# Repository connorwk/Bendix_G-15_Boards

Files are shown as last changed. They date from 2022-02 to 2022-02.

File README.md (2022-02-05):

# Bendix G-15 Boards
KiCad re-creations of the schematics and boards for the Bendix G-15.

These boards are meant to be functional drop in replacements for the original boards, whether they are damaged or missing.
The idea is either:
- To drill out the rivets on the original card's frames, desolder the wires for the tube sockets/etc and rivet/solder in the new board.
- Build up oragami PCBs to build a card frame.

Currently the goal is to get all schematics and boards layed out for the G-15 CPU and get a CPU at the System Source Computer Museum up and running using replacement boards.

## TODO
- Find suitable replacement diodes/transistors. This will be determined by component parameter analysis, specification comparison, and functional testing of boards with replaced components.
- Add oragami PCBs to allow building your own card handles to assemble around the boards.

## References
Documentation for the Bendix G-15 can be found here:
http://bitsavers.org/pdf/bendix/g-15/

The document used for schematics is:
http://bitsavers.org/pdf/bendix/g-15/G15D_Tech_Man_Rev1_Part1.pdf

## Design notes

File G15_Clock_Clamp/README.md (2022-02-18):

# Clock Clamp, For Bendix G-15 CPU
[Schematic](G15_Clock_Clamp_Schematic.pdf)

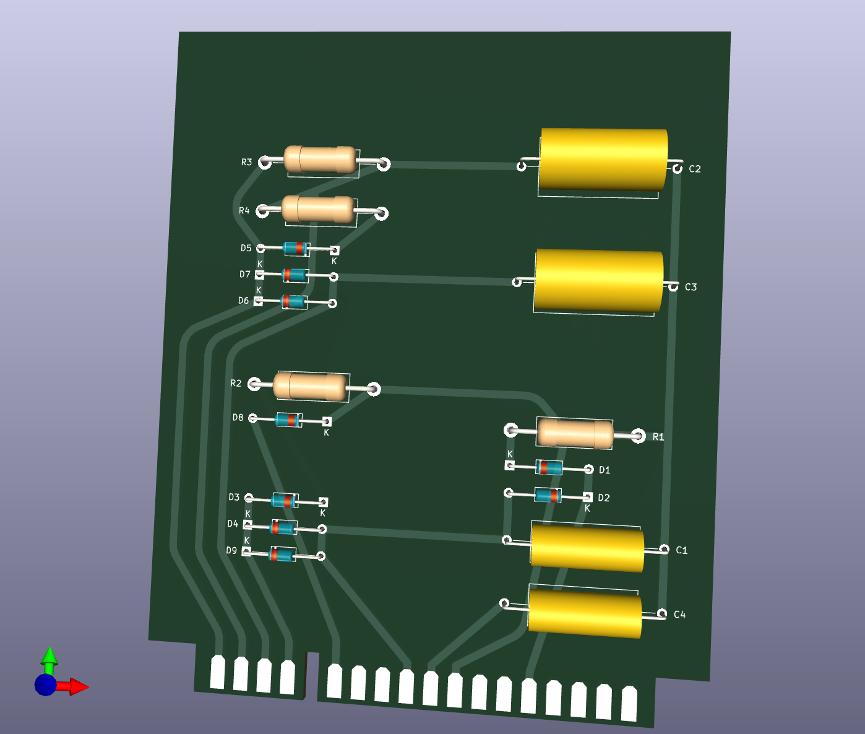
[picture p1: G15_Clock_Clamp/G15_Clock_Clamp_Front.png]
Front

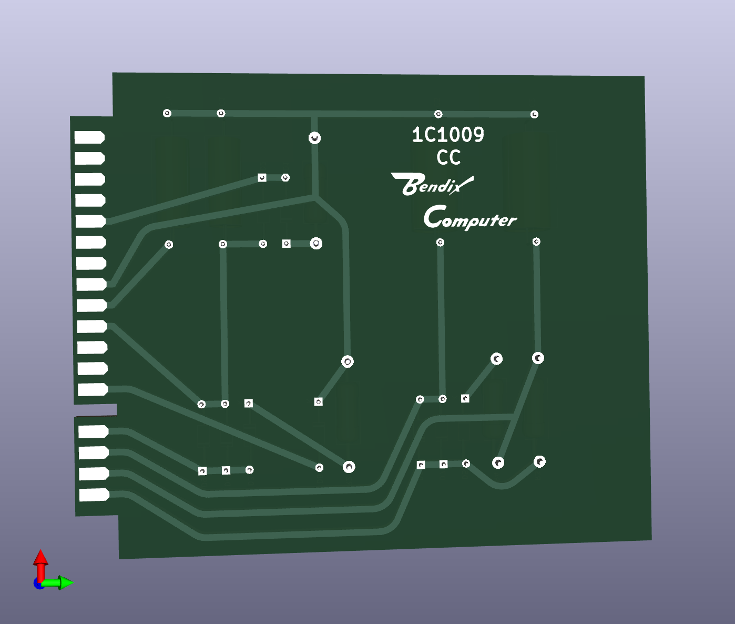
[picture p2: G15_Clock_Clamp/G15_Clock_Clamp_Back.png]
Back


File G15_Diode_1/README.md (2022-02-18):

# Diode 1, For Bendix G-15 CPU
[Schematic](G15_Diode_1_Schematic.pdf)

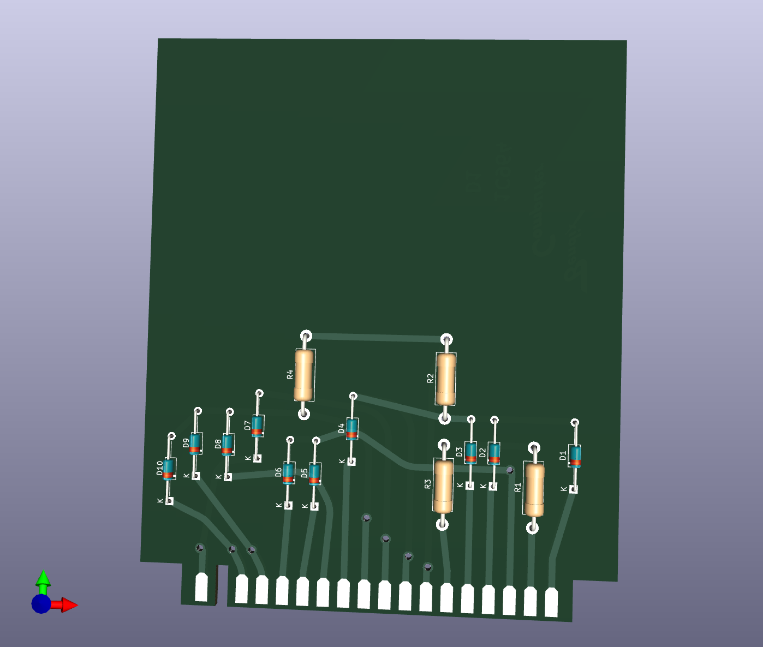
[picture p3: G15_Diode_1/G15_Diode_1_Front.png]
Front

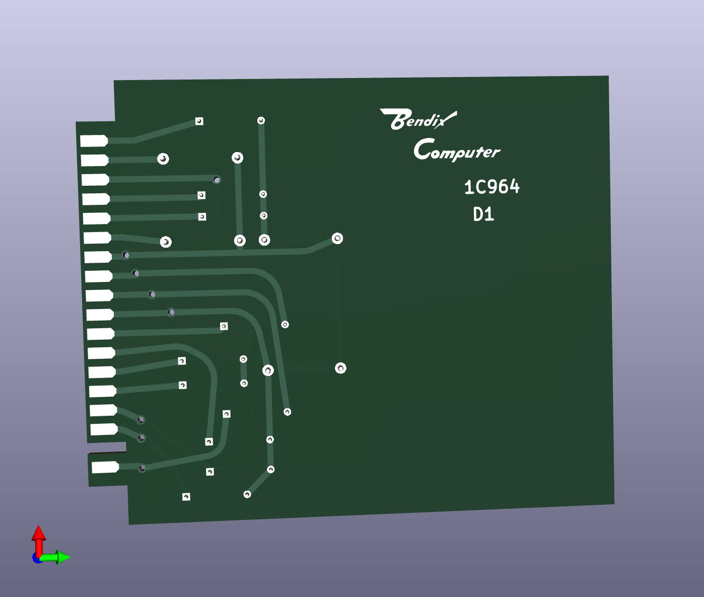
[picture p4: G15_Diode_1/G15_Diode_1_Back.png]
Back


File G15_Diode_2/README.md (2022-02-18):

# Diode 2, For Bendix G-15 CPU
[Schematic](G15_Diode_2_Schematic.pdf)

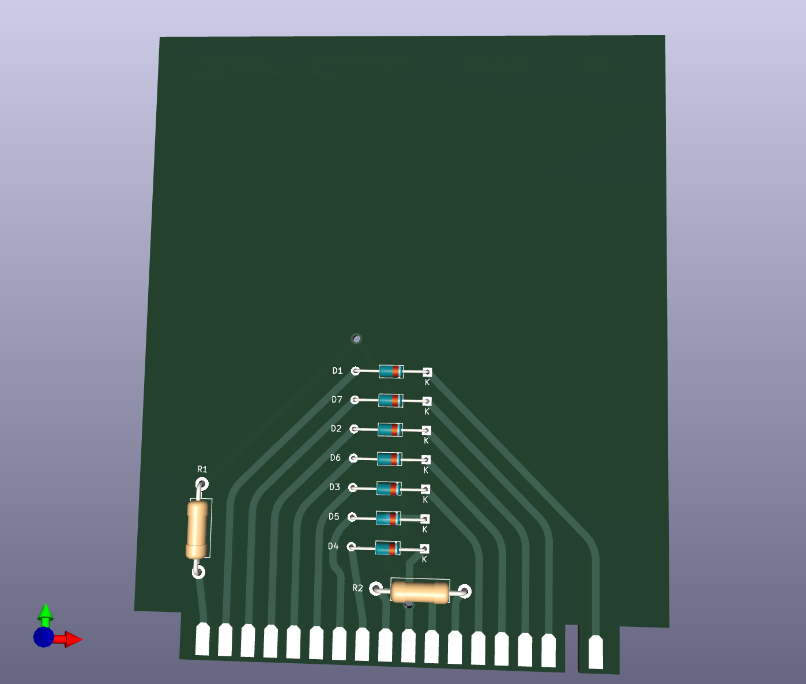
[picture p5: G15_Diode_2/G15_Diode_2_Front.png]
Front

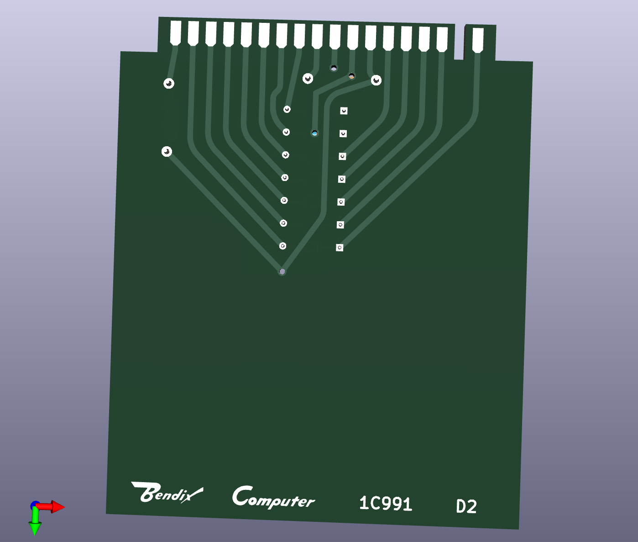
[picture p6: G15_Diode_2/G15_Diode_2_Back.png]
Back


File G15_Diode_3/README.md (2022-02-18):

# Diode 3, For Bendix G-15 CPU
[Schematic](G15_Diode_3_Schematic.pdf)

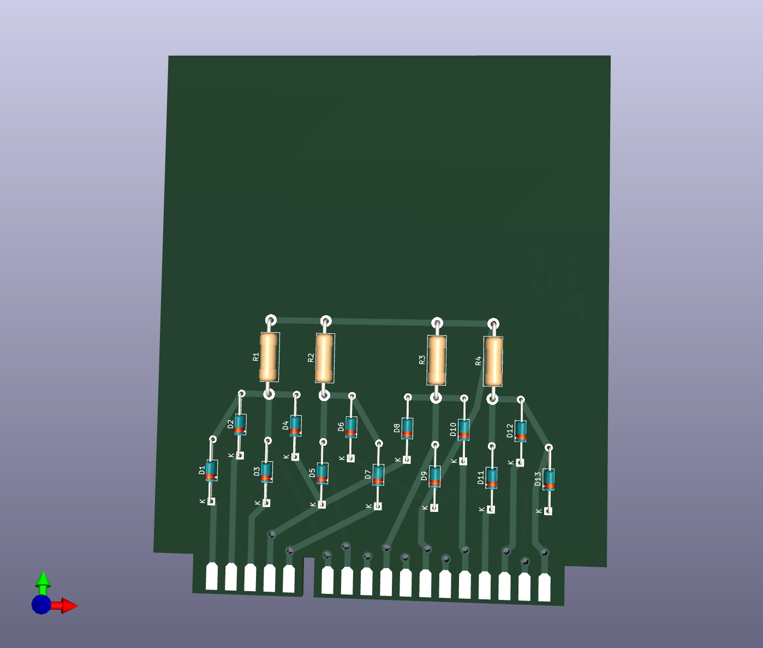
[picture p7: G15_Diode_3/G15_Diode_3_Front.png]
Front

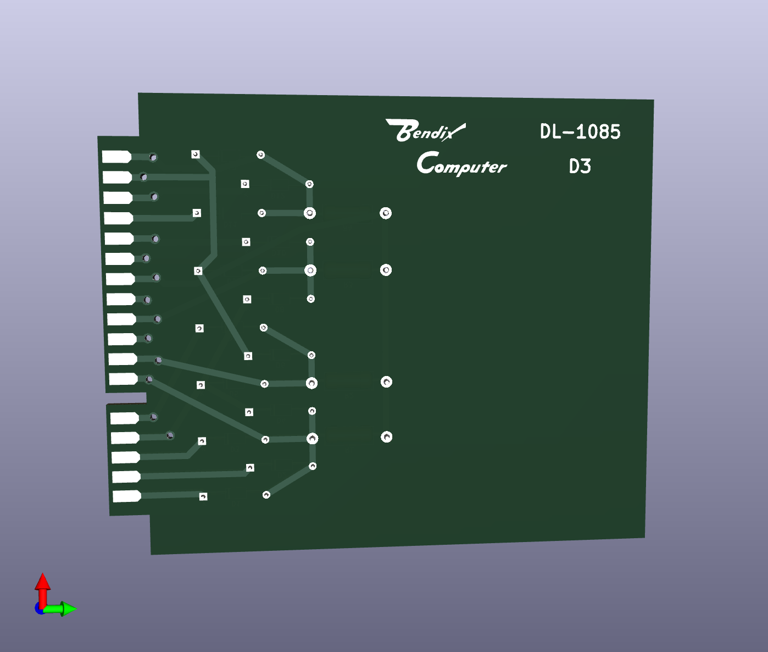
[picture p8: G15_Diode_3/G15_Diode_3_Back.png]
Back


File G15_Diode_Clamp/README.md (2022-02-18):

# Diode ClamP, For Bendix G-15 CPU
[Schematic](G15_Diode_Clamp_Schematic.pdf)

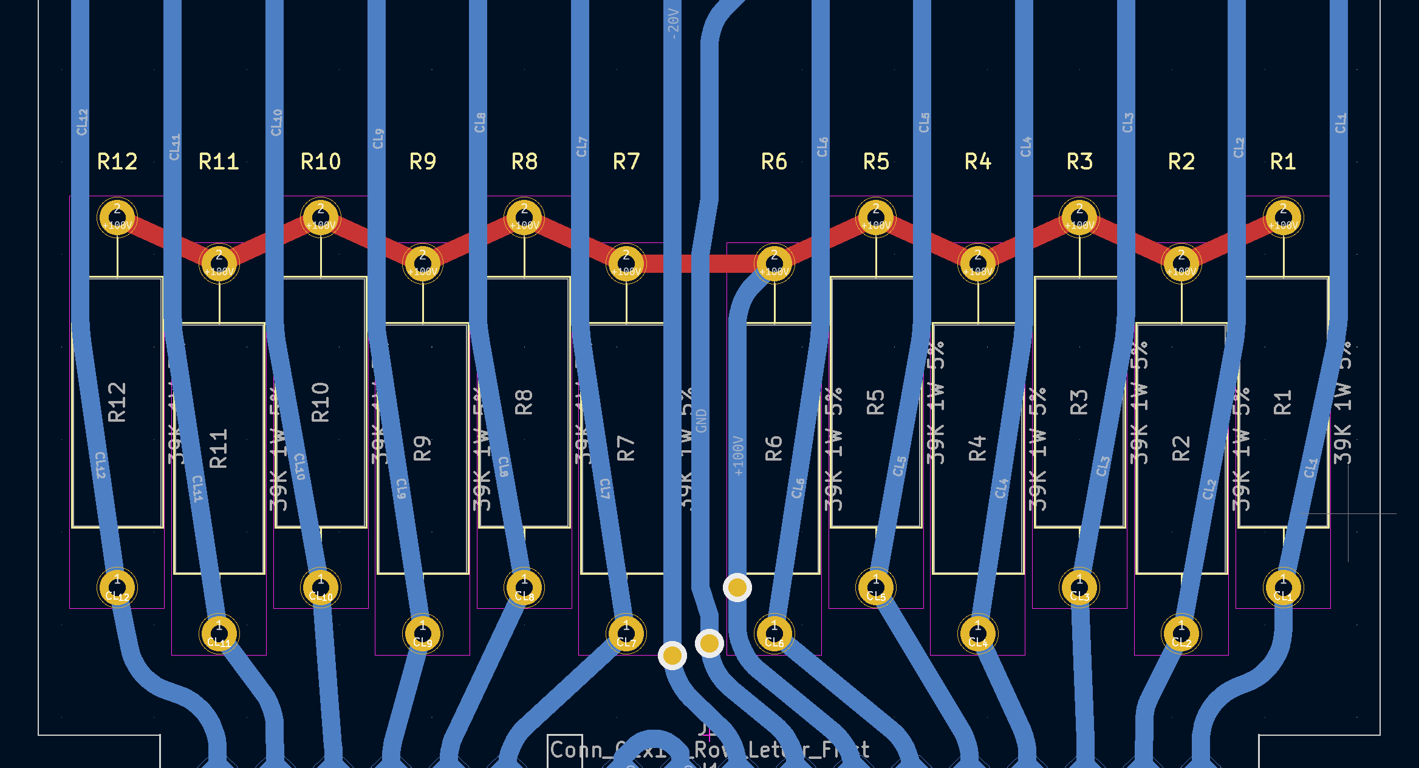
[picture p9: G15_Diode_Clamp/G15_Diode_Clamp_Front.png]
Front

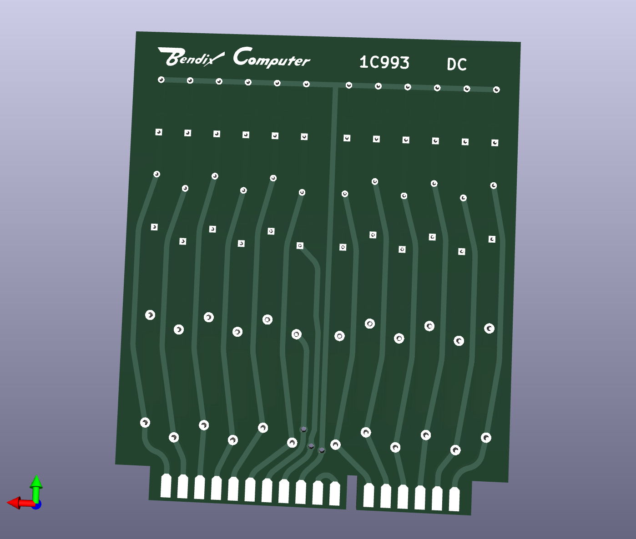
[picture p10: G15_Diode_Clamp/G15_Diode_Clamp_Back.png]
Back


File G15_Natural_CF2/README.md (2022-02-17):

# Cathode Follower 2, Natural Handle, For Bendix G-15 CPU
[Schematic](G15_Natural_CF2_Schematic.pdf)

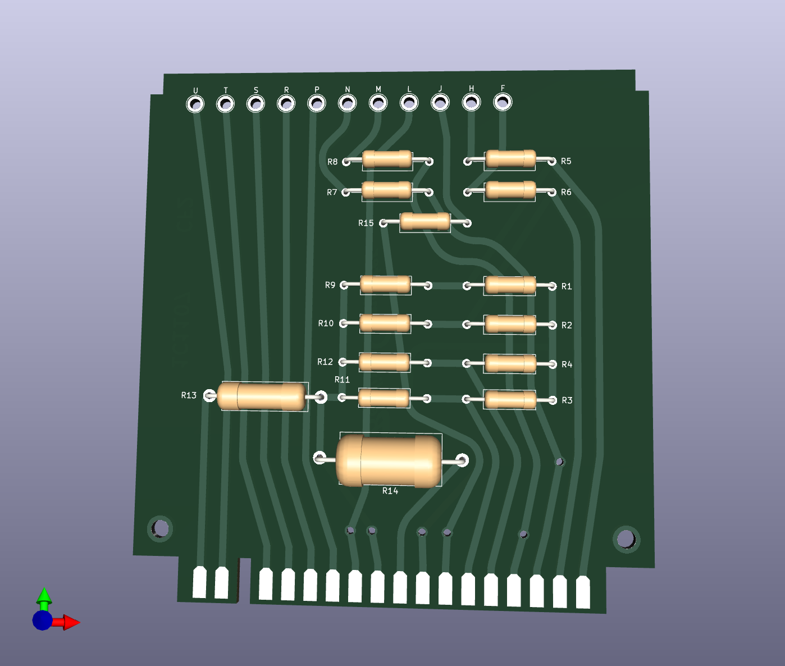
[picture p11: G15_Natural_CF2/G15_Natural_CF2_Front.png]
Front

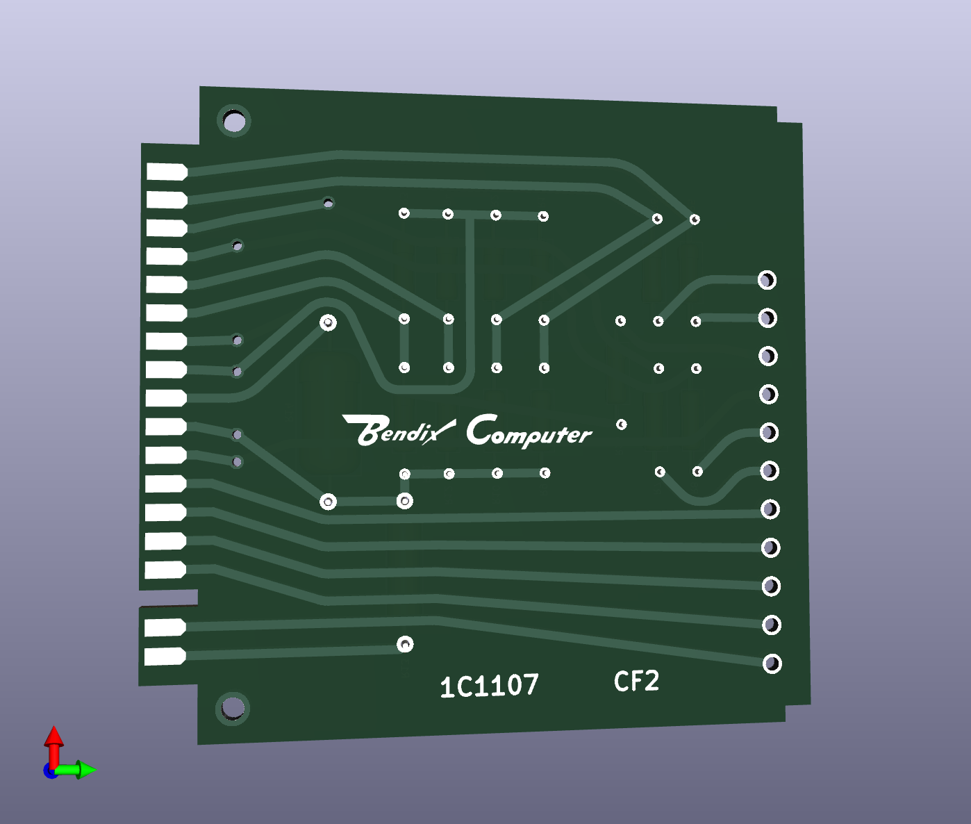
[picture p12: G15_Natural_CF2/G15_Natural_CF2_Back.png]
Back


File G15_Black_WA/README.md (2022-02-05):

# Write Amplifier, Black Handle, For Bendix G-15 CPU
[Schematic](G15_Black_WA_Schematic.pdf)

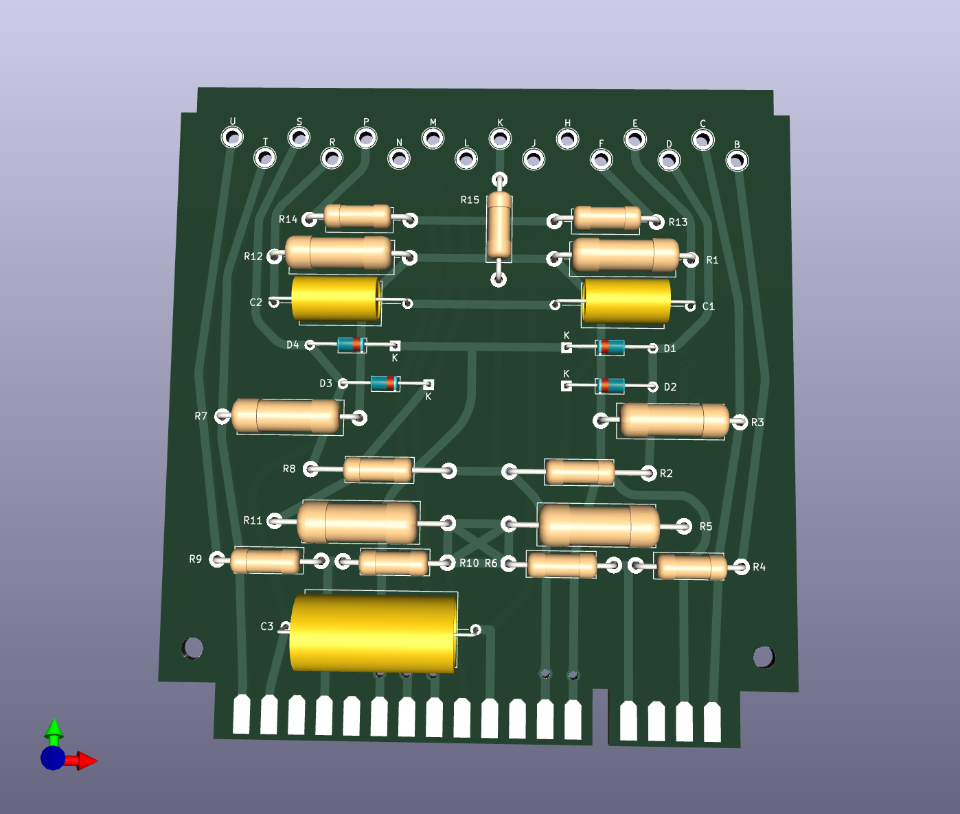
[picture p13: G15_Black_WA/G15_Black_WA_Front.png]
Front

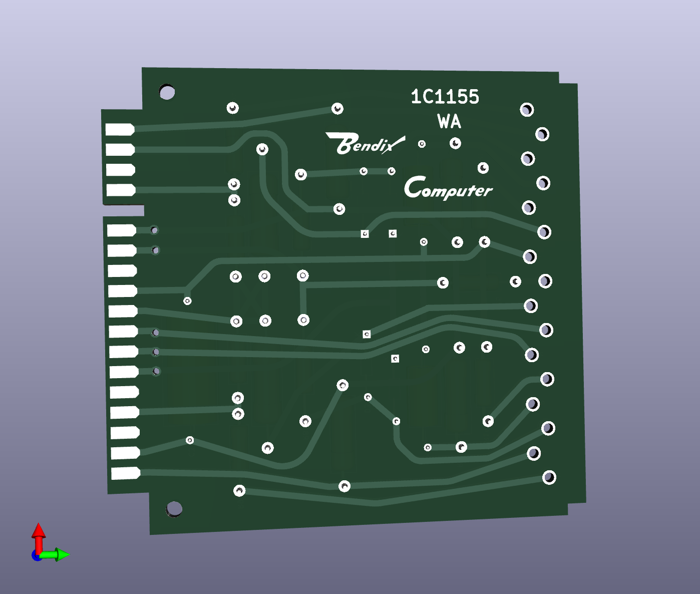
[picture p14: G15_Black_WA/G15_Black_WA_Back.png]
Back


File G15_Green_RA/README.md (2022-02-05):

# Read Amplifier, Green Handle, For Bendix G-15 CPU
[Schematic](G15_Green_RA_Schematic.pdf)

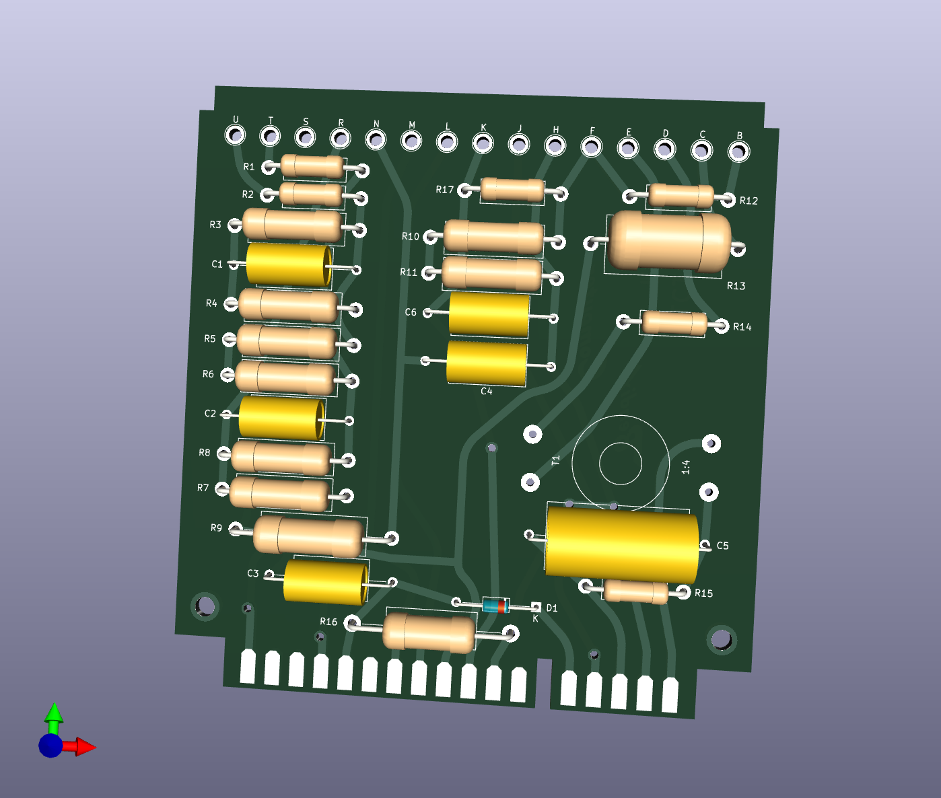
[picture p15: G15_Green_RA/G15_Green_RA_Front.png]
Front

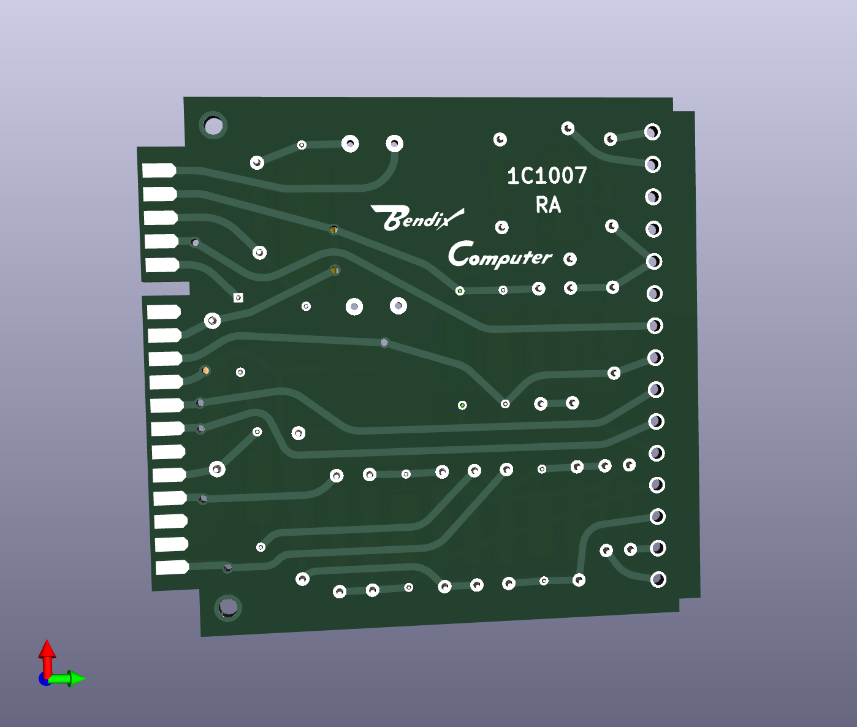
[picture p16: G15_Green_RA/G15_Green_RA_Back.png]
Back


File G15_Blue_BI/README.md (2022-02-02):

# Buffer Inverter, Blue Handle, For Bendix G-15 CPU
[Schematic](G15_Blue_BI_Schematic.pdf)

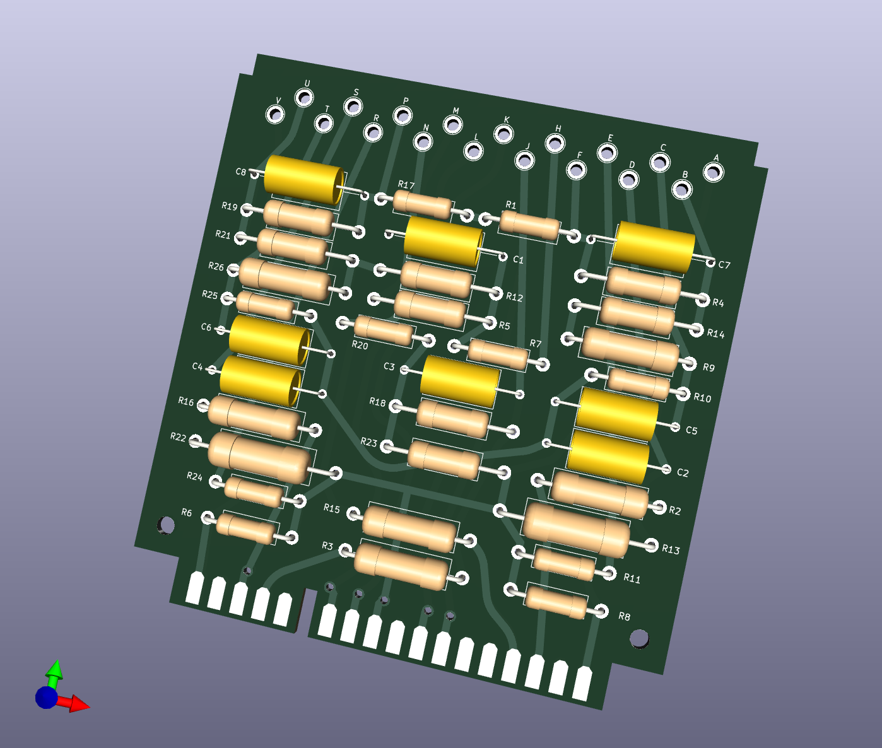
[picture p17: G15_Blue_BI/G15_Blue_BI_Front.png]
Front

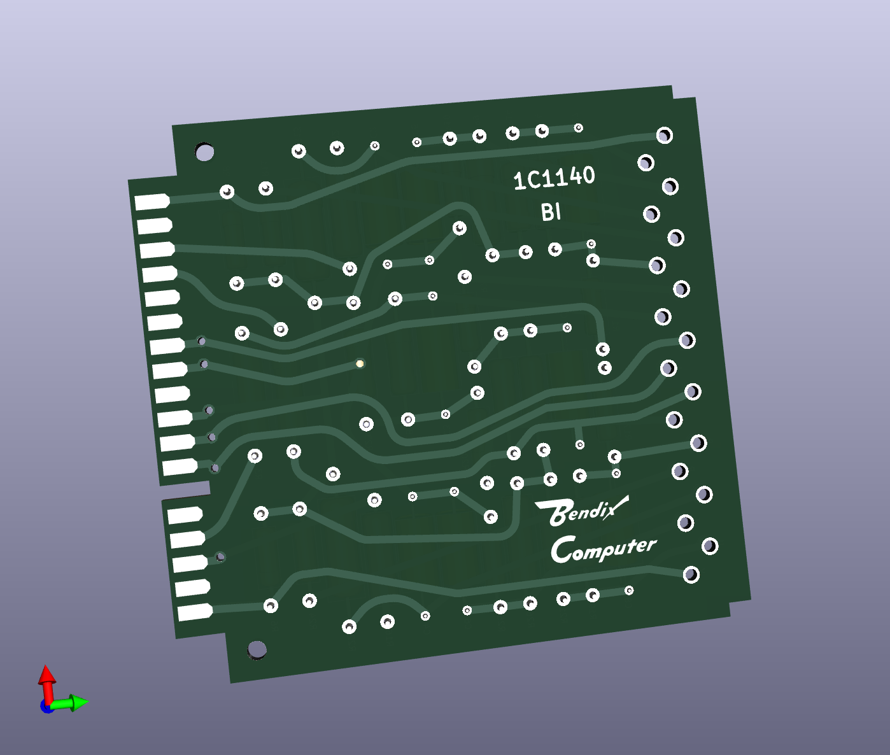
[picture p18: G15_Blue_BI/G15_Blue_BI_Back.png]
Back


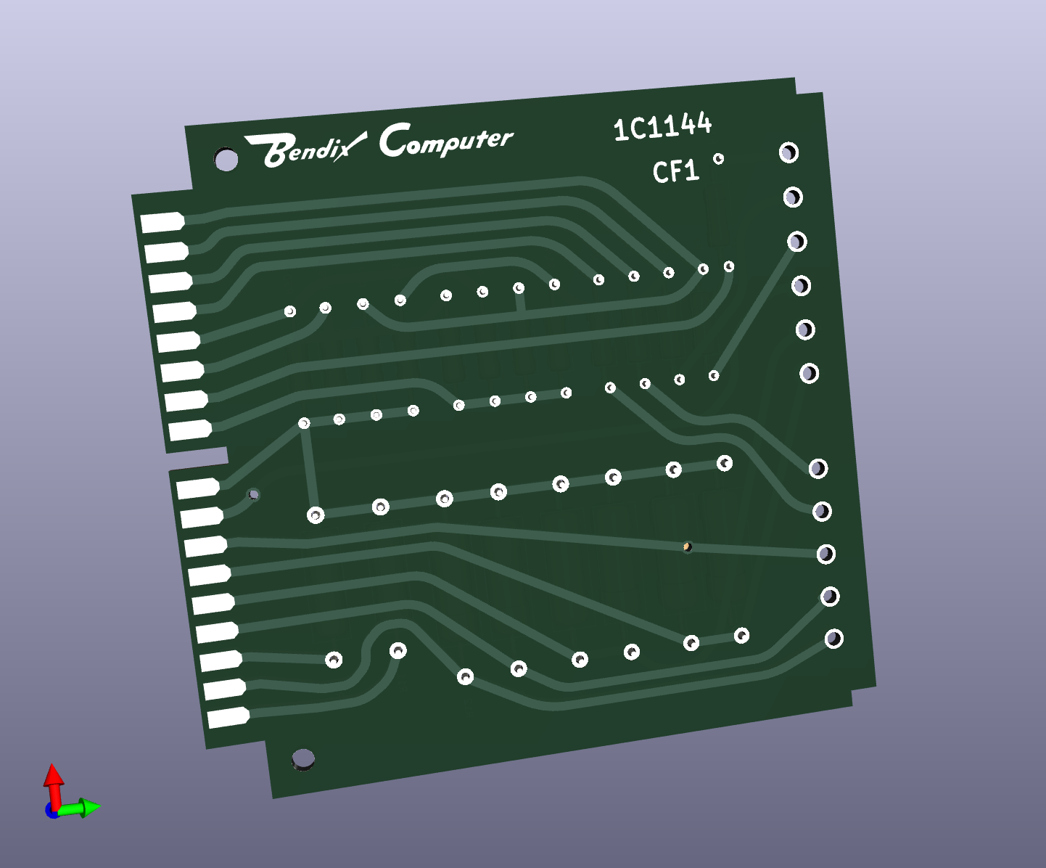
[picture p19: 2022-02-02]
G15_Red_CF1/G15_Red_CF1_Back.png

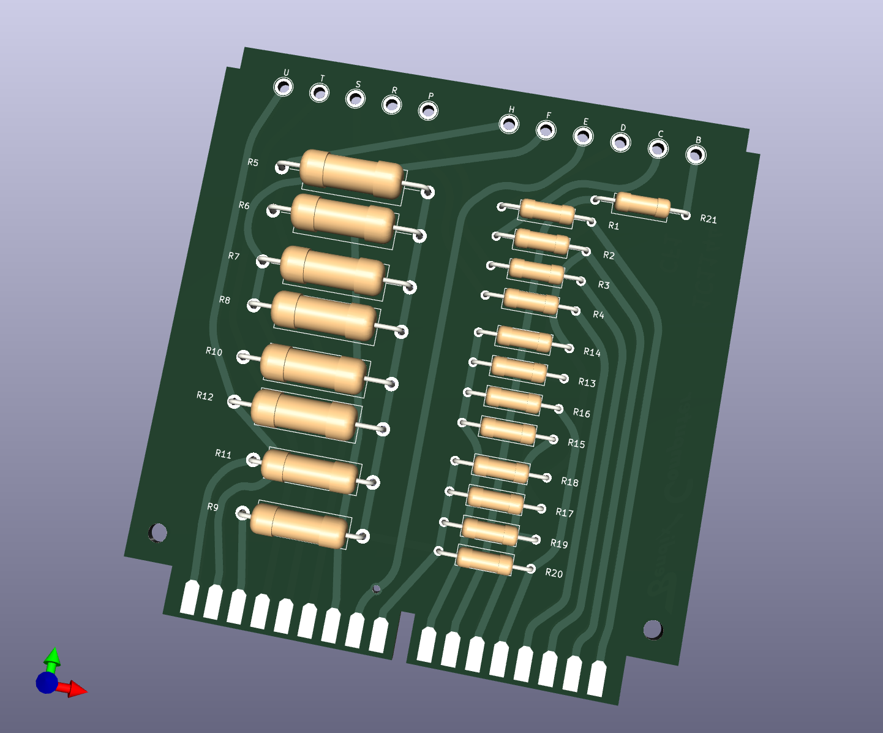
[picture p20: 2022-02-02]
G15_Red_CF1/G15_Red_CF1_Front.png

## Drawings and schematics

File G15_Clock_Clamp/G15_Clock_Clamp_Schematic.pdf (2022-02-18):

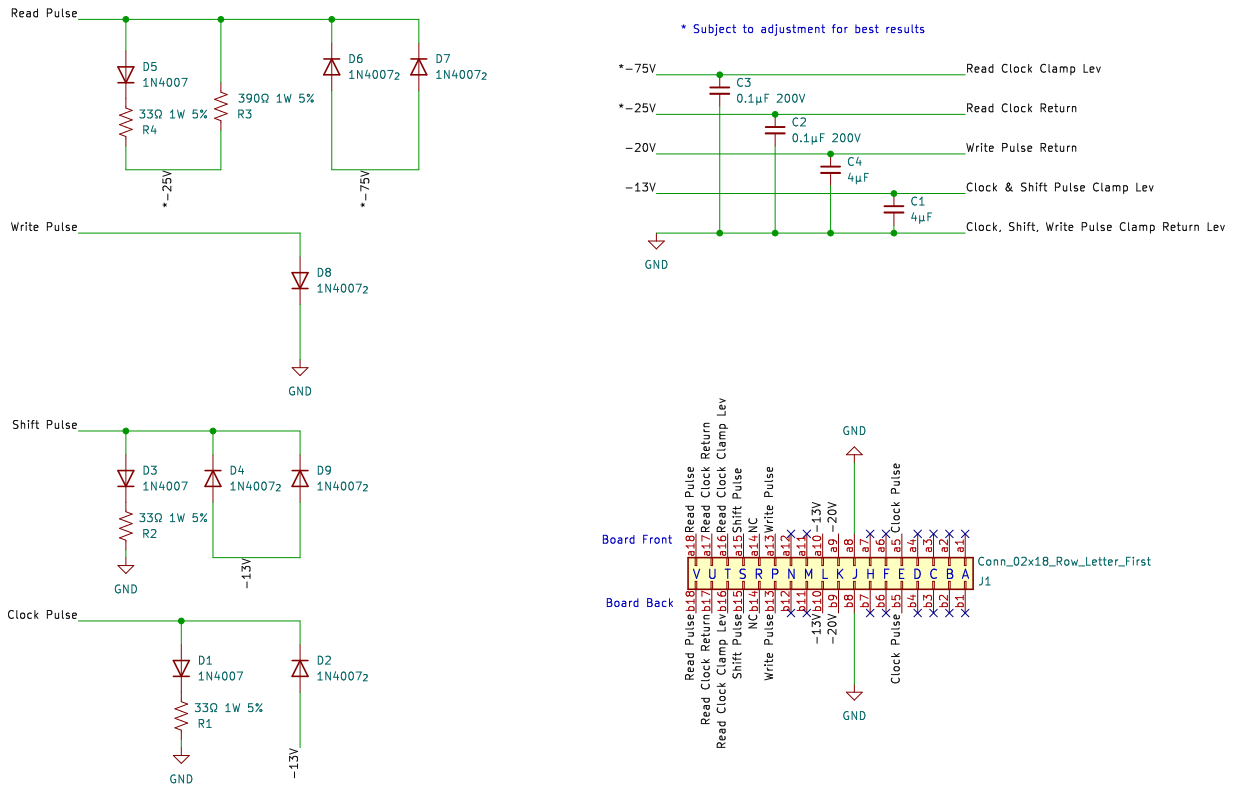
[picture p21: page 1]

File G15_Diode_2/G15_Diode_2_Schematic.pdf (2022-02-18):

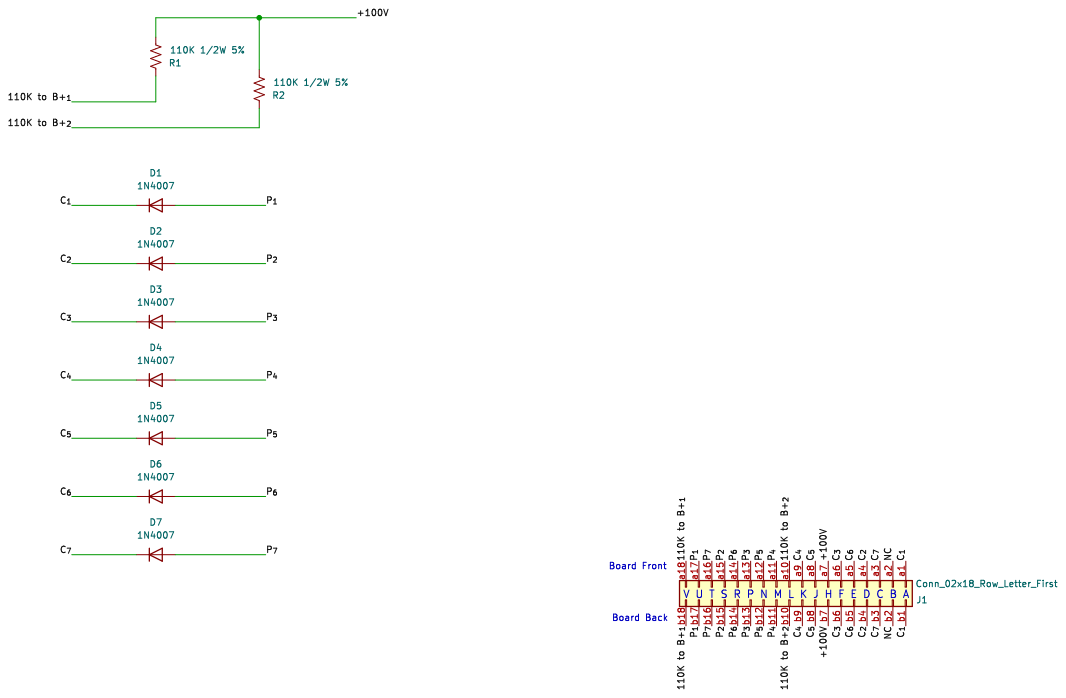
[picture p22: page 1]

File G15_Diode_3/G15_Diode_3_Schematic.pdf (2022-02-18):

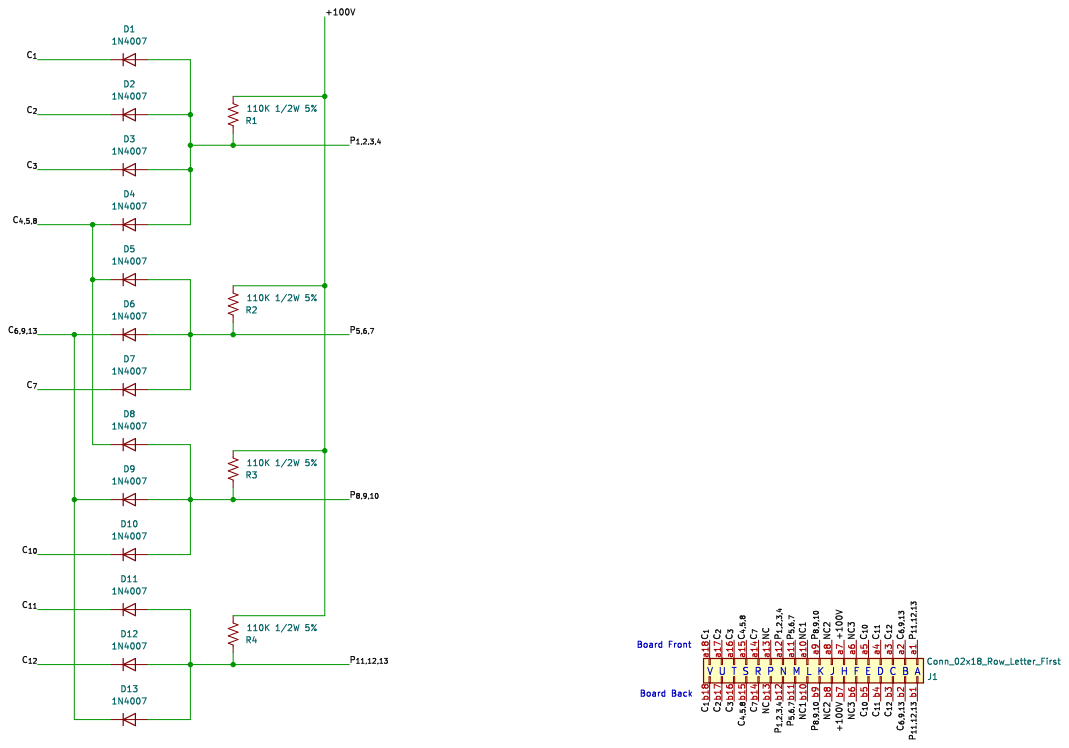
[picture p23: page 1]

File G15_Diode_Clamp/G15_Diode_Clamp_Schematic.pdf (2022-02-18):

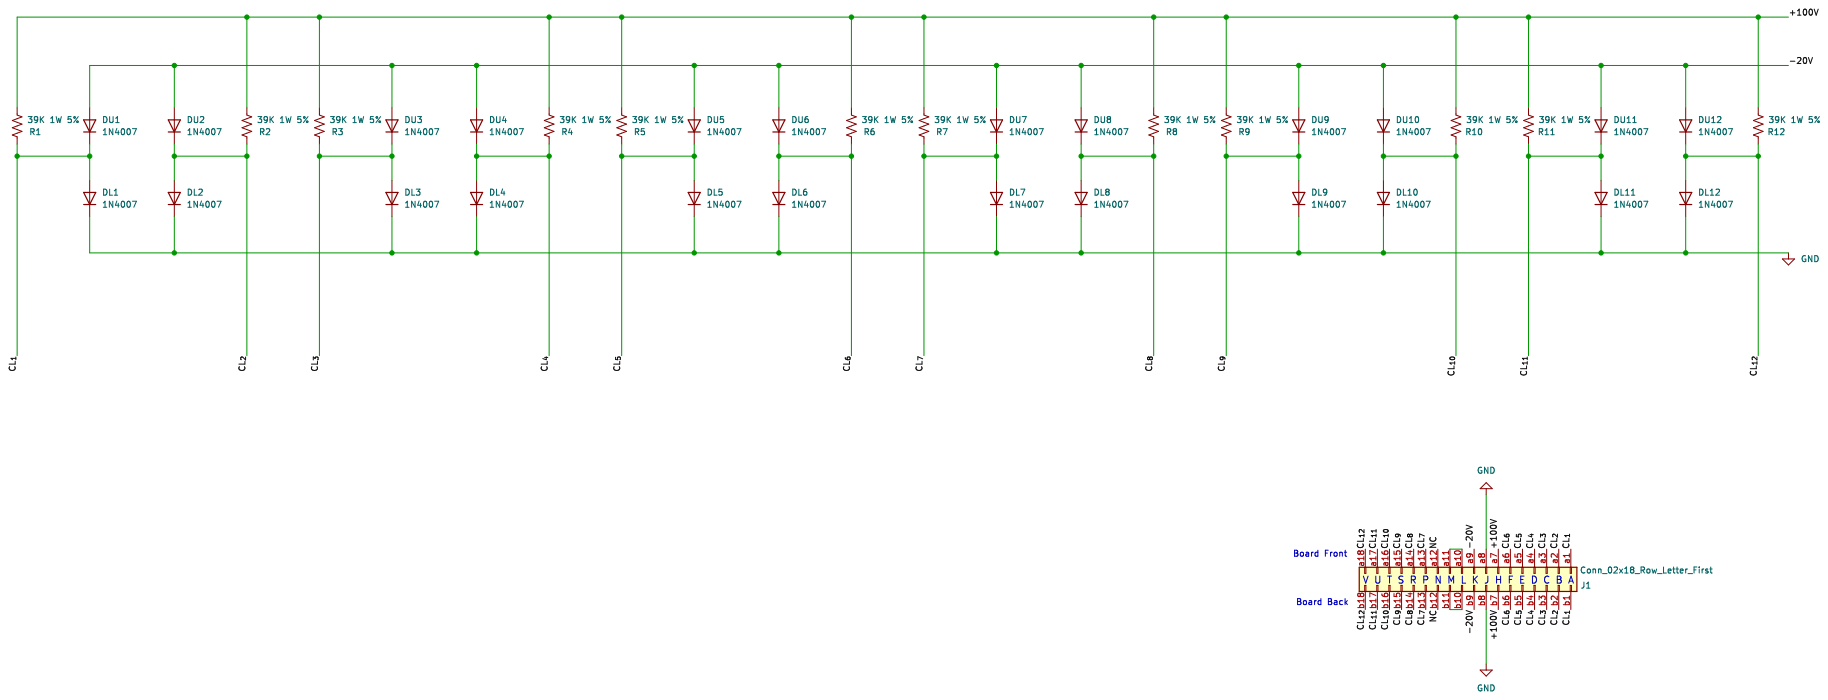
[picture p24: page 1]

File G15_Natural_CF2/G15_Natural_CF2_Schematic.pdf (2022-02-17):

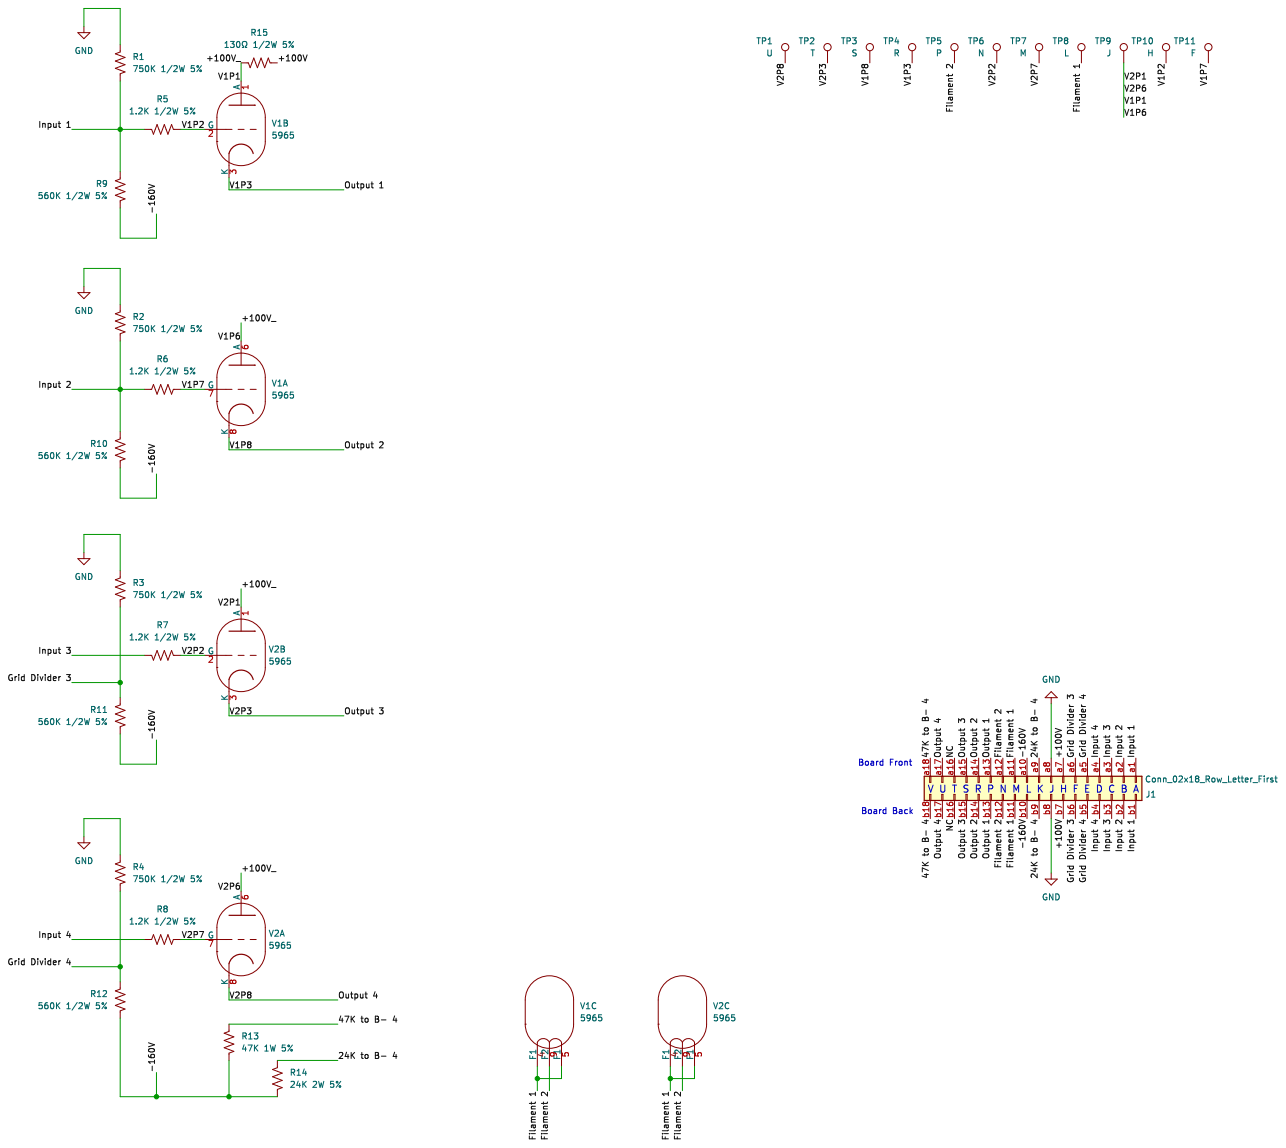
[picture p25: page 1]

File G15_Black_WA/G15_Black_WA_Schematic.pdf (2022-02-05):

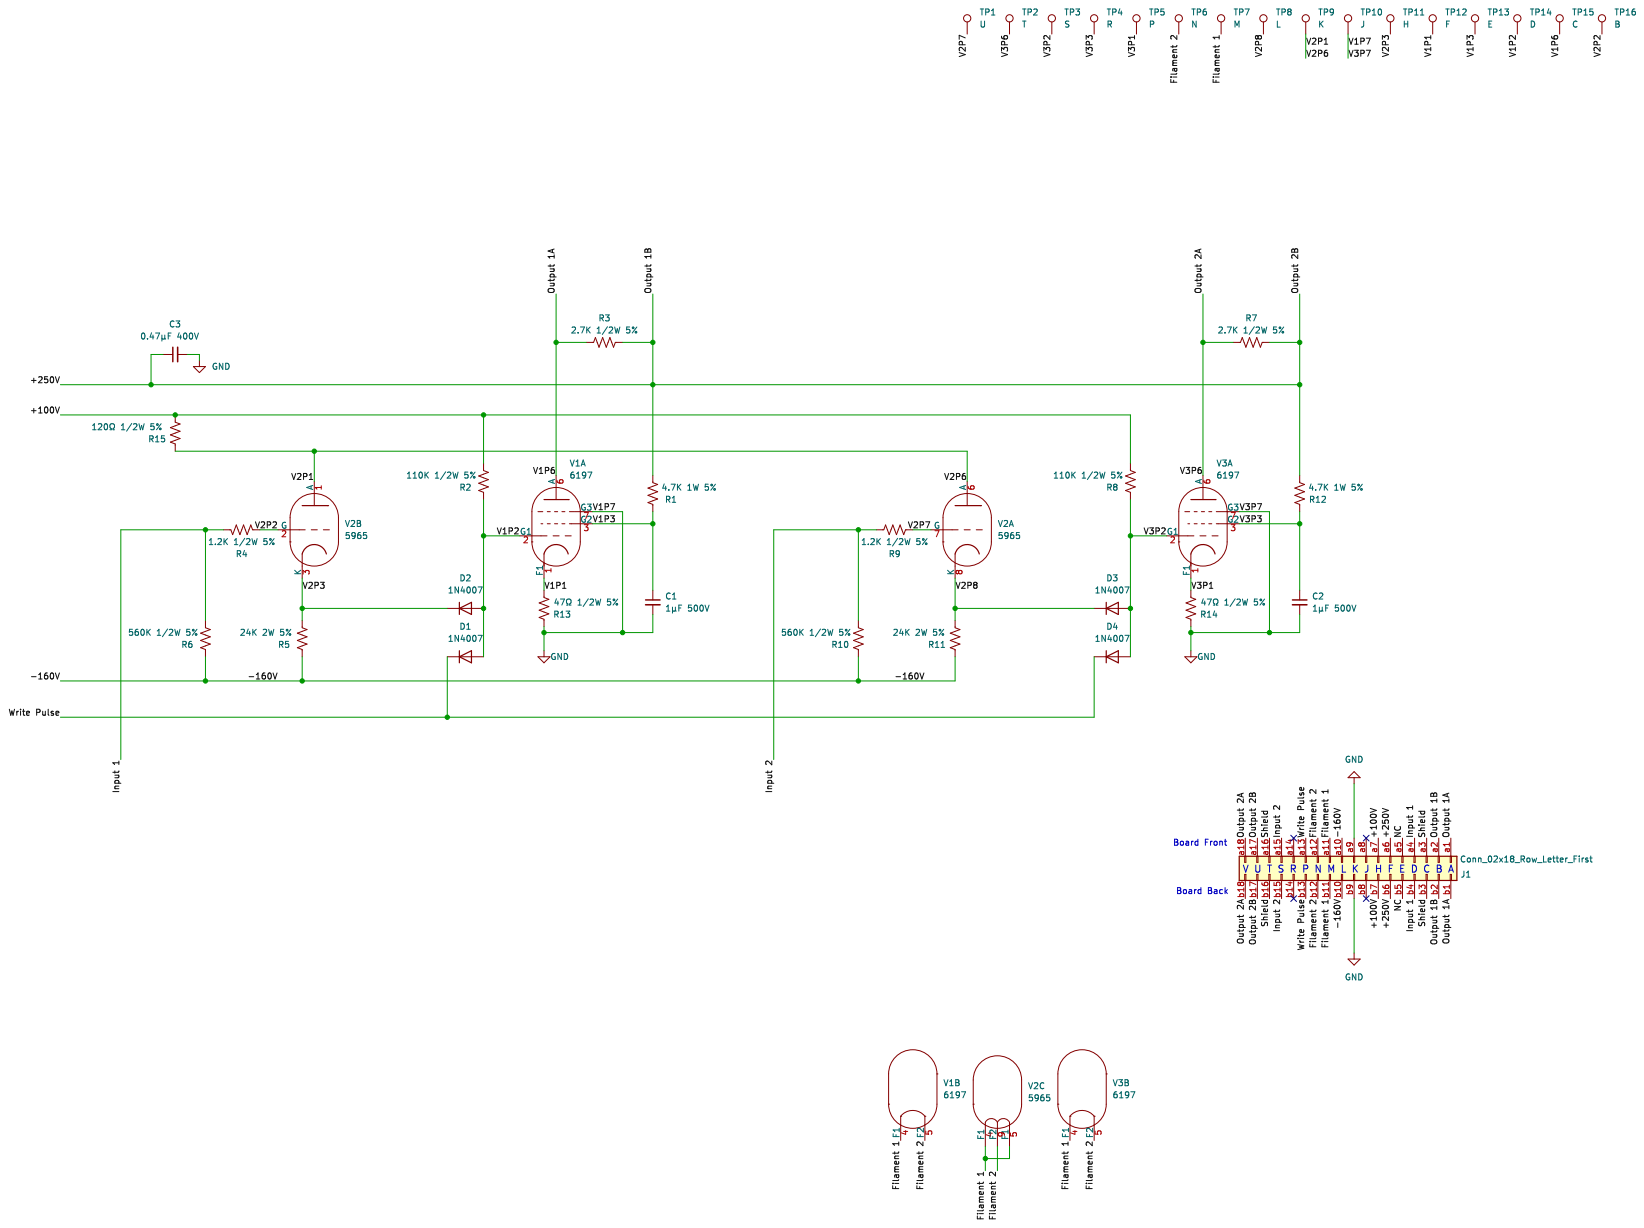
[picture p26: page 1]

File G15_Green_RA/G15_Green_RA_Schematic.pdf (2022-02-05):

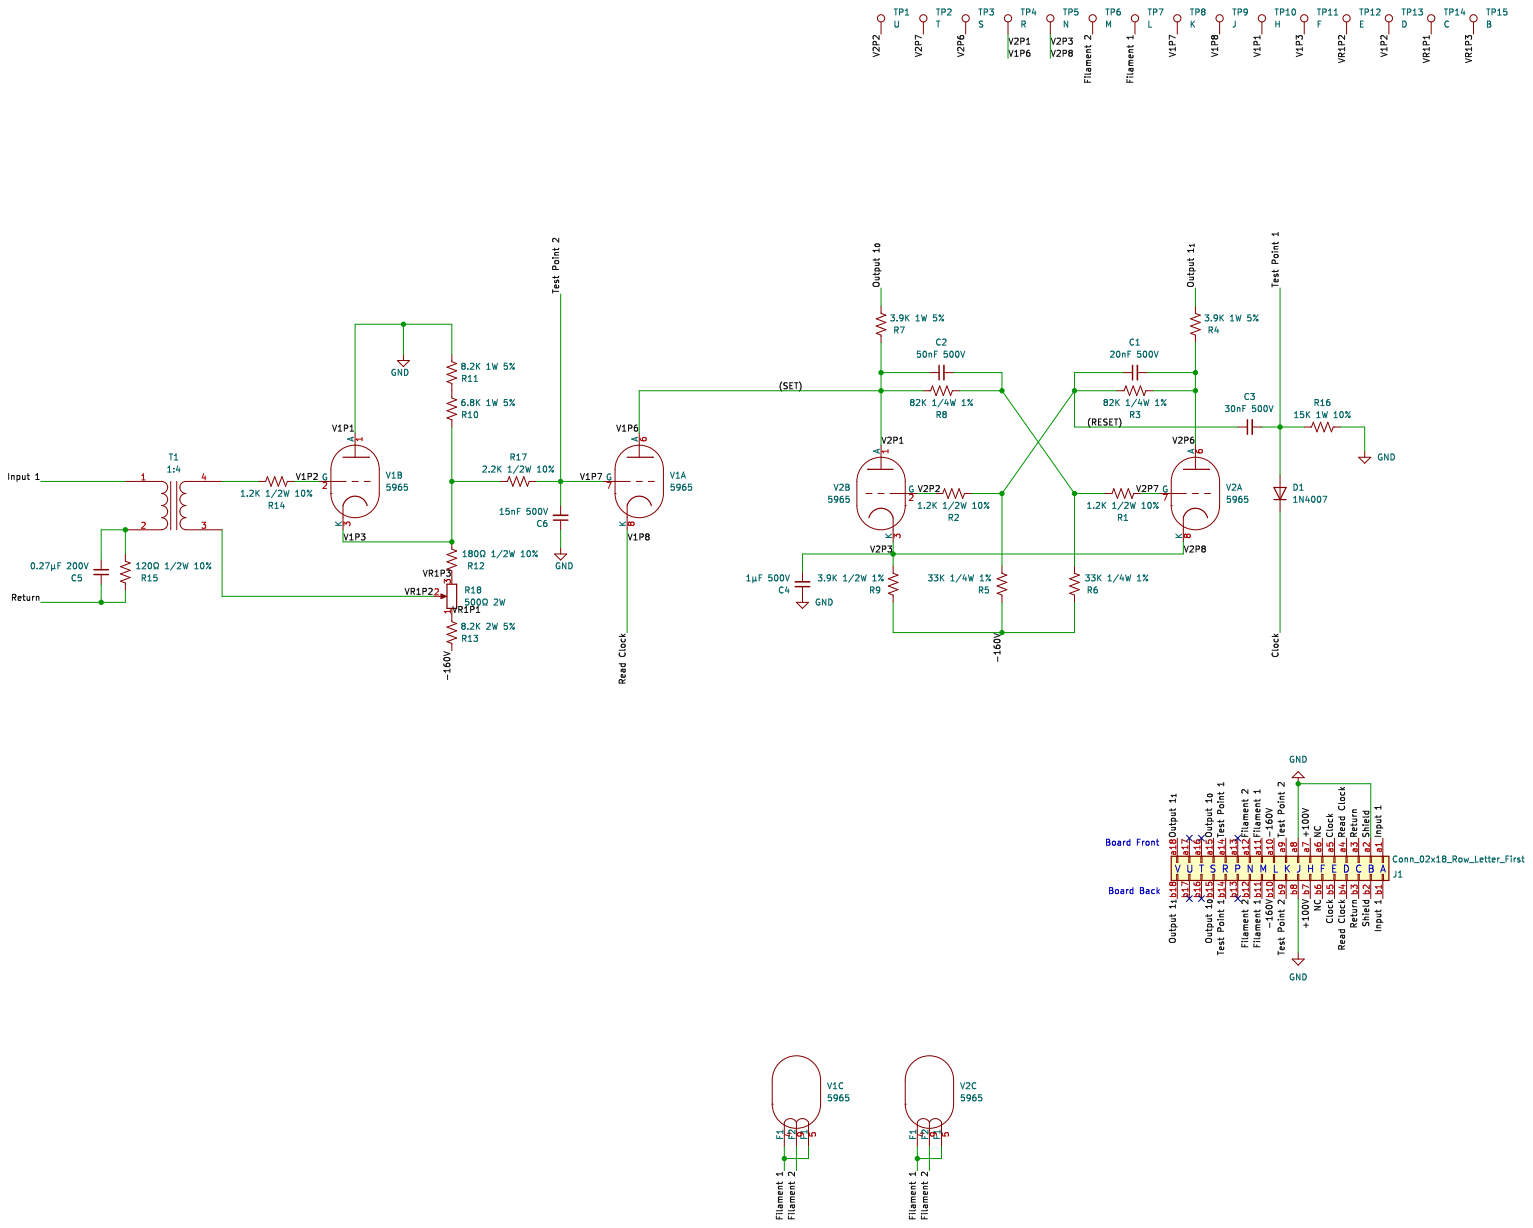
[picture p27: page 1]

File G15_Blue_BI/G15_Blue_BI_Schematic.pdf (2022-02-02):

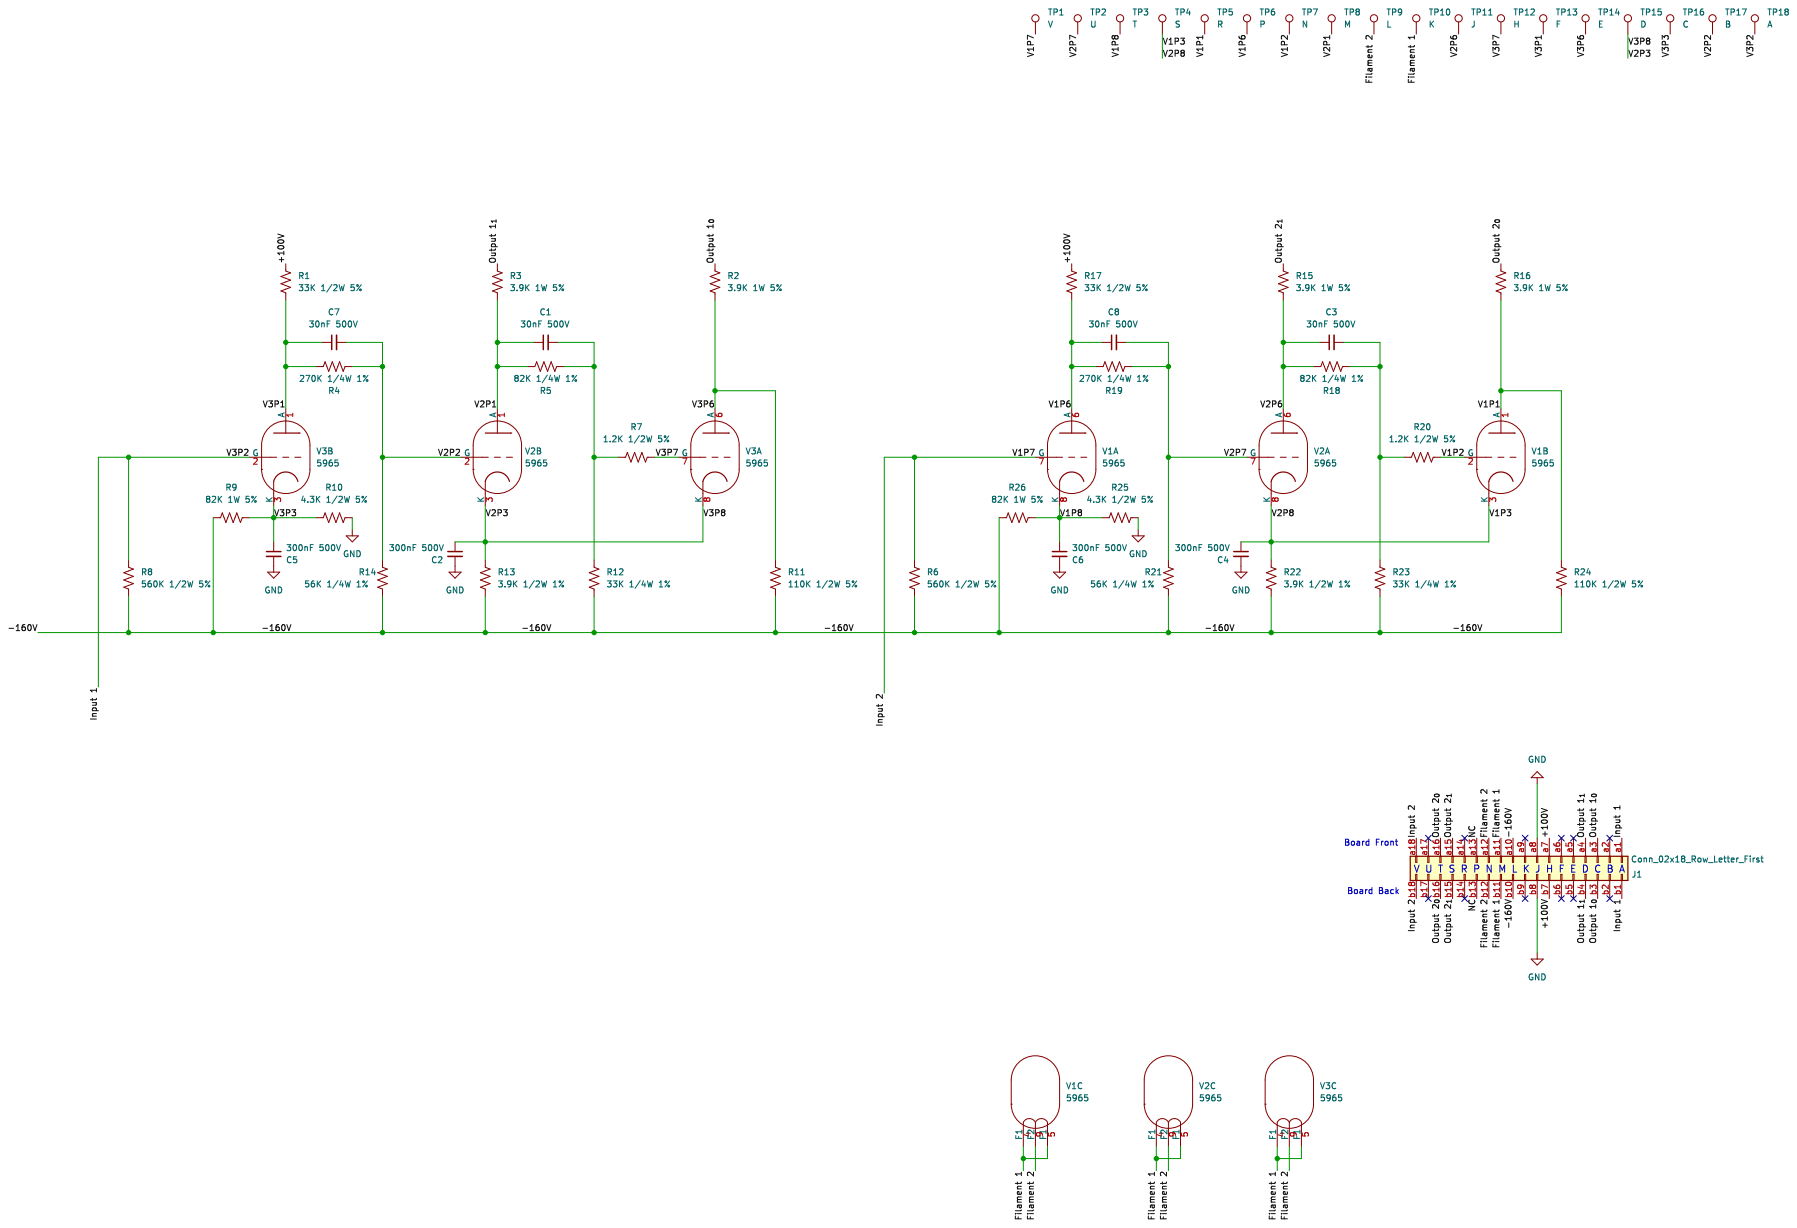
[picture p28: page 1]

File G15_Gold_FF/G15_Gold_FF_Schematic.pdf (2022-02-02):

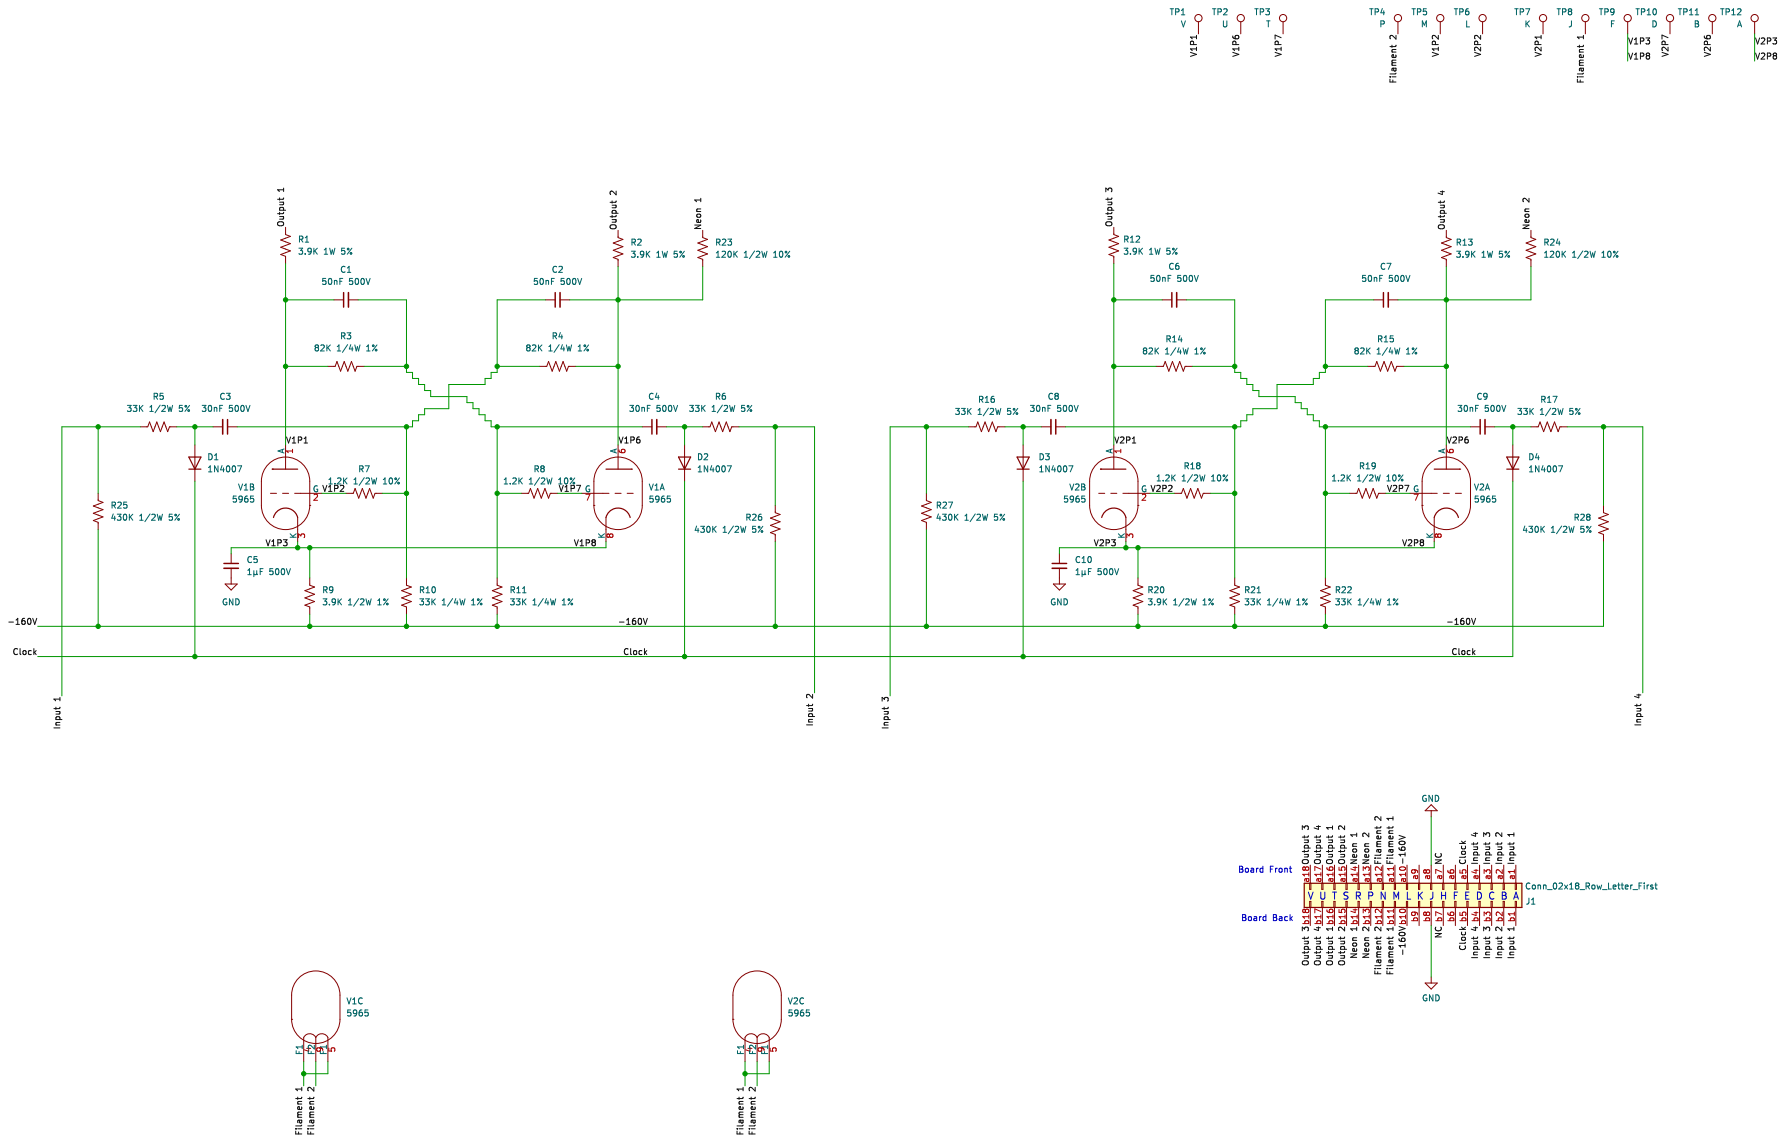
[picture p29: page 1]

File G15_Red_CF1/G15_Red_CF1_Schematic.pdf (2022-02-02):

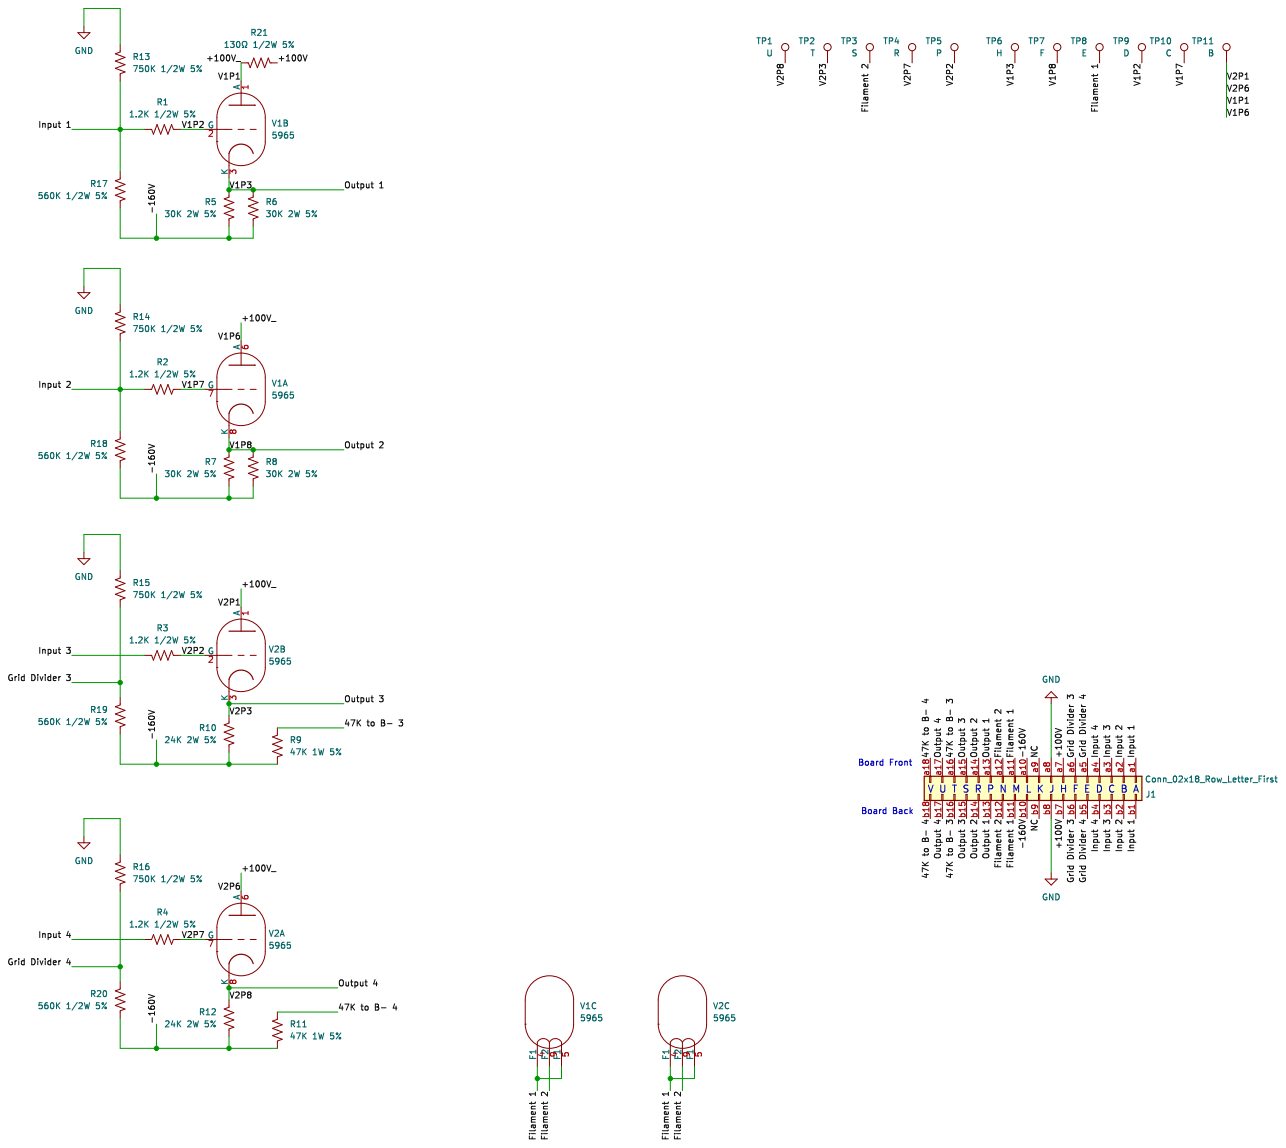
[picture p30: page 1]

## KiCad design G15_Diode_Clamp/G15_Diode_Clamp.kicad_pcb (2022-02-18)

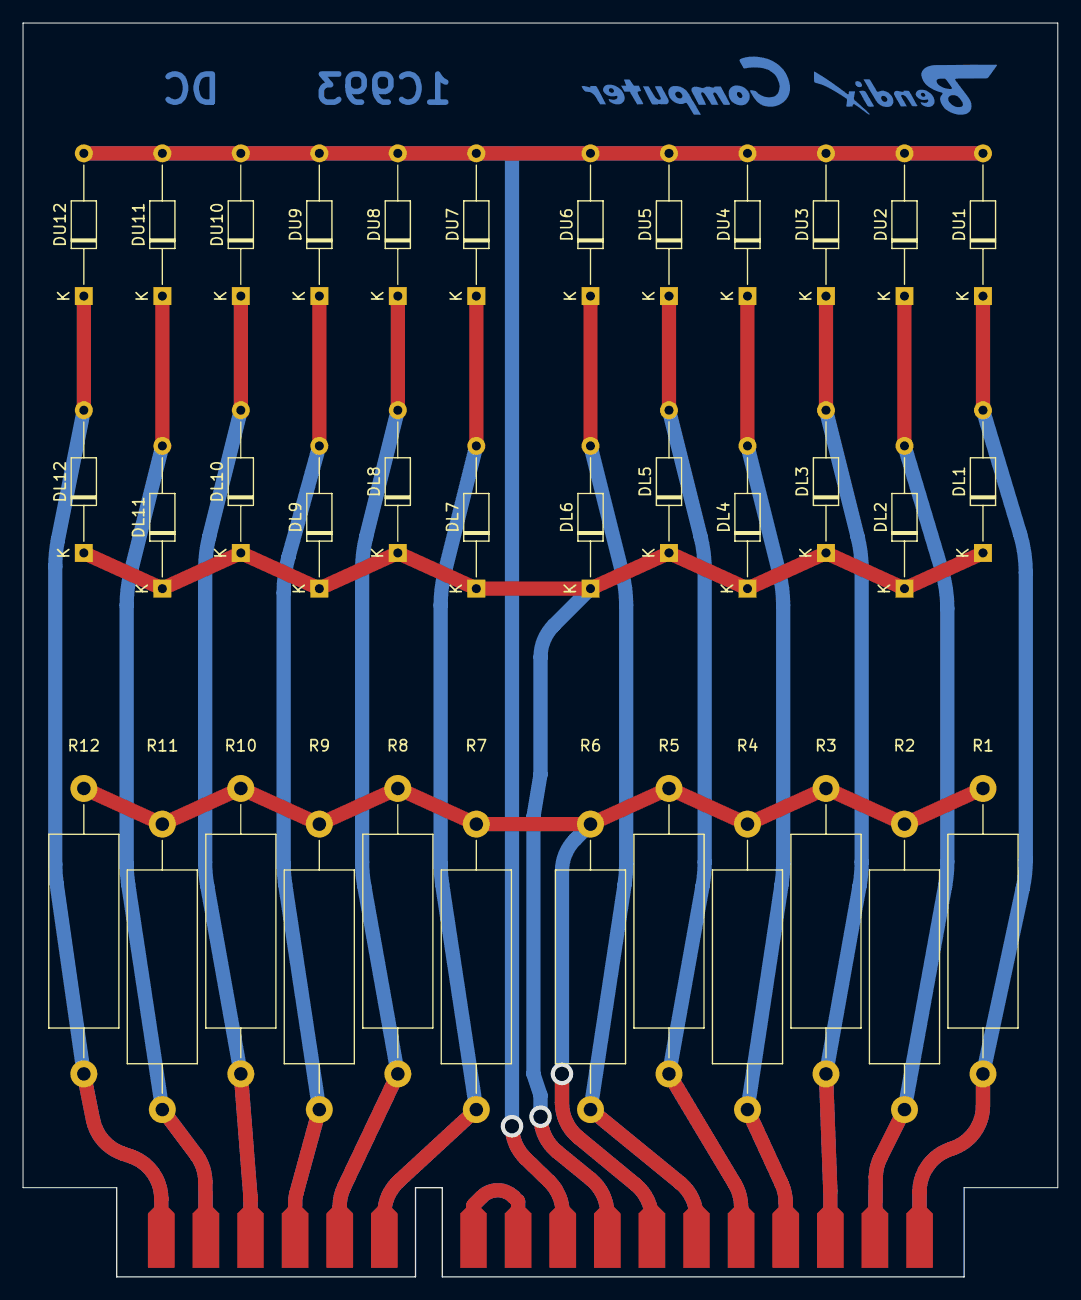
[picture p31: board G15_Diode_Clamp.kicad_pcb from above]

Board: 2 copper layers, 92.1 x 111.6 mm, 37 parts (0 on the bottom side), 17 nets.

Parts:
DL1, DL2, DL3, DL4, DL5, DL6, DL7, DL8, DL9, DL10, DL11, DL12: 1N4007; D_DO-35_SOD27_P12.70mm_Horizontal
DU1, DU2, DU3, DU4, DU5, DU6, DU7, DU8, DU9, DU10, DU11, DU12: 1N4007; D_DO-35_SOD27_P12.70mm_Horizontal
J1: Conn_02x18_Row_Letter_First; Card_Edge_N_Key
R1, R2, R3, R4, R5, R6, R7, R8, R9, R10, R11, R12: 39K 1W 5%; R_Axial_DIN0617_L17.0mm_D6.0mm_P25.40mm_Horizontal

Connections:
/+100V: J1.a7, J1.b7, R1.2, R2.2, R3.2, R4.2, R5.2, R6.2, R7.2, R8.2, R9.2, R10.2, R11.2, R12.2
/-20V: DU1.2 (A), DU2.2 (A), DU3.2 (A), DU4.2 (A), DU5.2 (A), DU6.2 (A), DU7.2 (A), DU8.2 (A), DU9.2 (A), DU10.2 (A), DU11.2 (A), DU12.2 (A), J1.a9, J1.b9
/CL_{1}: DL1.2 (A), DU1.1 (K), J1.a1, J1.b1, R1.1
/CL_{2}: DL2.2 (A), DU2.1 (K), J1.a2, J1.b2, R2.1
/CL_{3}: DL3.2 (A), DU3.1 (K), J1.a3, J1.b3, R3.1
/CL_{4}: DL4.2 (A), DU4.1 (K), J1.a4, J1.b4, R4.1
/CL_{5}: DL5.2 (A), DU5.1 (K), J1.a5, J1.b5, R5.1
/CL_{6}: DL6.2 (A), DU6.1 (K), J1.a6, J1.b6, R6.1
/CL_{7}: DL7.2 (A), DU7.1 (K), J1.a13, J1.b13, R7.1
/CL_{8}: DL8.2 (A), DU8.1 (K), J1.a14, J1.b14, R8.1
/CL_{9}: DL9.2 (A), DU9.1 (K), J1.a15, J1.b15, R9.1
/CL_{10}: DL10.2 (A), DU10.1 (K), J1.a16, J1.b16, R10.1
/CL_{11}: DL11.2 (A), DU11.1 (K), J1.a17, J1.b17, R11.1
/CL_{12}: DL12.2 (A), DU12.1 (K), J1.a18, J1.b18, R12.1
GND: DL1.1 (K), DL2.1 (K), DL3.1 (K), DL4.1 (K), DL5.1 (K), DL6.1 (K), DL7.1 (K), DL8.1 (K), DL9.1 (K), DL10.1 (K), DL11.1 (K), DL12.1 (K), J1.a8, J1.b8
unnamed: J1.a10, J1.a11
unnamed: J1.b10, J1.b11

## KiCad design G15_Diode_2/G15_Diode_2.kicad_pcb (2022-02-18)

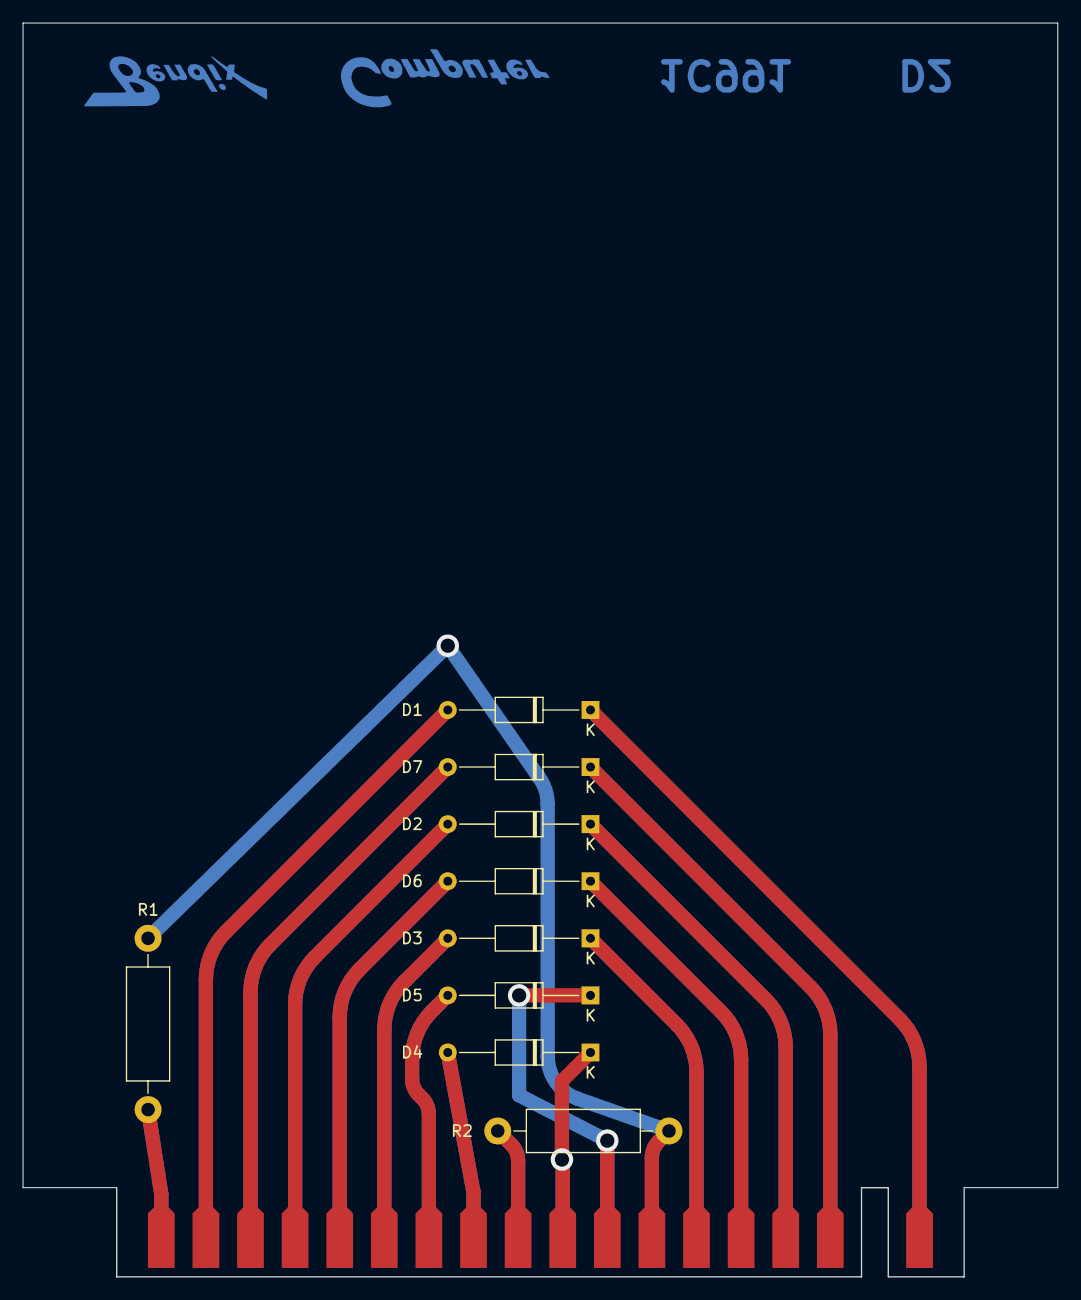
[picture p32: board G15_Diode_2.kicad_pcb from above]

Board: 2 copper layers, 92.1 x 111.6 mm, 10 parts (0 on the bottom side), 17 nets.

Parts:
D1, D2, D3, D4, D5, D6, D7: 1N4007; D_DO-35_SOD27_P12.70mm_Horizontal
J1: Conn_02x18_Row_Letter_First; Card_Edge_B_Key
R1, R2: 110K 1/2W 5%; R_Axial_DIN0411_L9.9mm_D3.6mm_P15.24mm_Horizontal

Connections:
/110K to B+_{1}: J1.a18, J1.b18, R1.1
/110K to B+_{2}: J1.a10, J1.b10, R2.1
/+100V: J1.a7, J1.b7, R1.2, R2.2
/C_{1}: D1.1 (K), J1.a1, J1.b1
/C_{2}: D2.1 (K), J1.a4, J1.b4
/C_{3}: D3.1 (K), J1.a6, J1.b6
/C_{4}: D4.1 (K), J1.a9, J1.b9
/C_{5}: D5.1 (K), J1.a8, J1.b8
/C_{6}: D6.1 (K), J1.a5, J1.b5
/C_{7}: D7.1 (K), J1.a3, J1.b3
/P_{1}: D1.2 (A), J1.a17, J1.b17
/P_{2}: D2.2 (A), J1.a15, J1.b15
/P_{3}: D3.2 (A), J1.a13, J1.b13
/P_{4}: D4.2 (A), J1.a11, J1.b11
/P_{5}: D5.2 (A), J1.a12, J1.b12
/P_{6}: D6.2 (A), J1.a14, J1.b14
/P_{7}: D7.2 (A), J1.a16, J1.b16

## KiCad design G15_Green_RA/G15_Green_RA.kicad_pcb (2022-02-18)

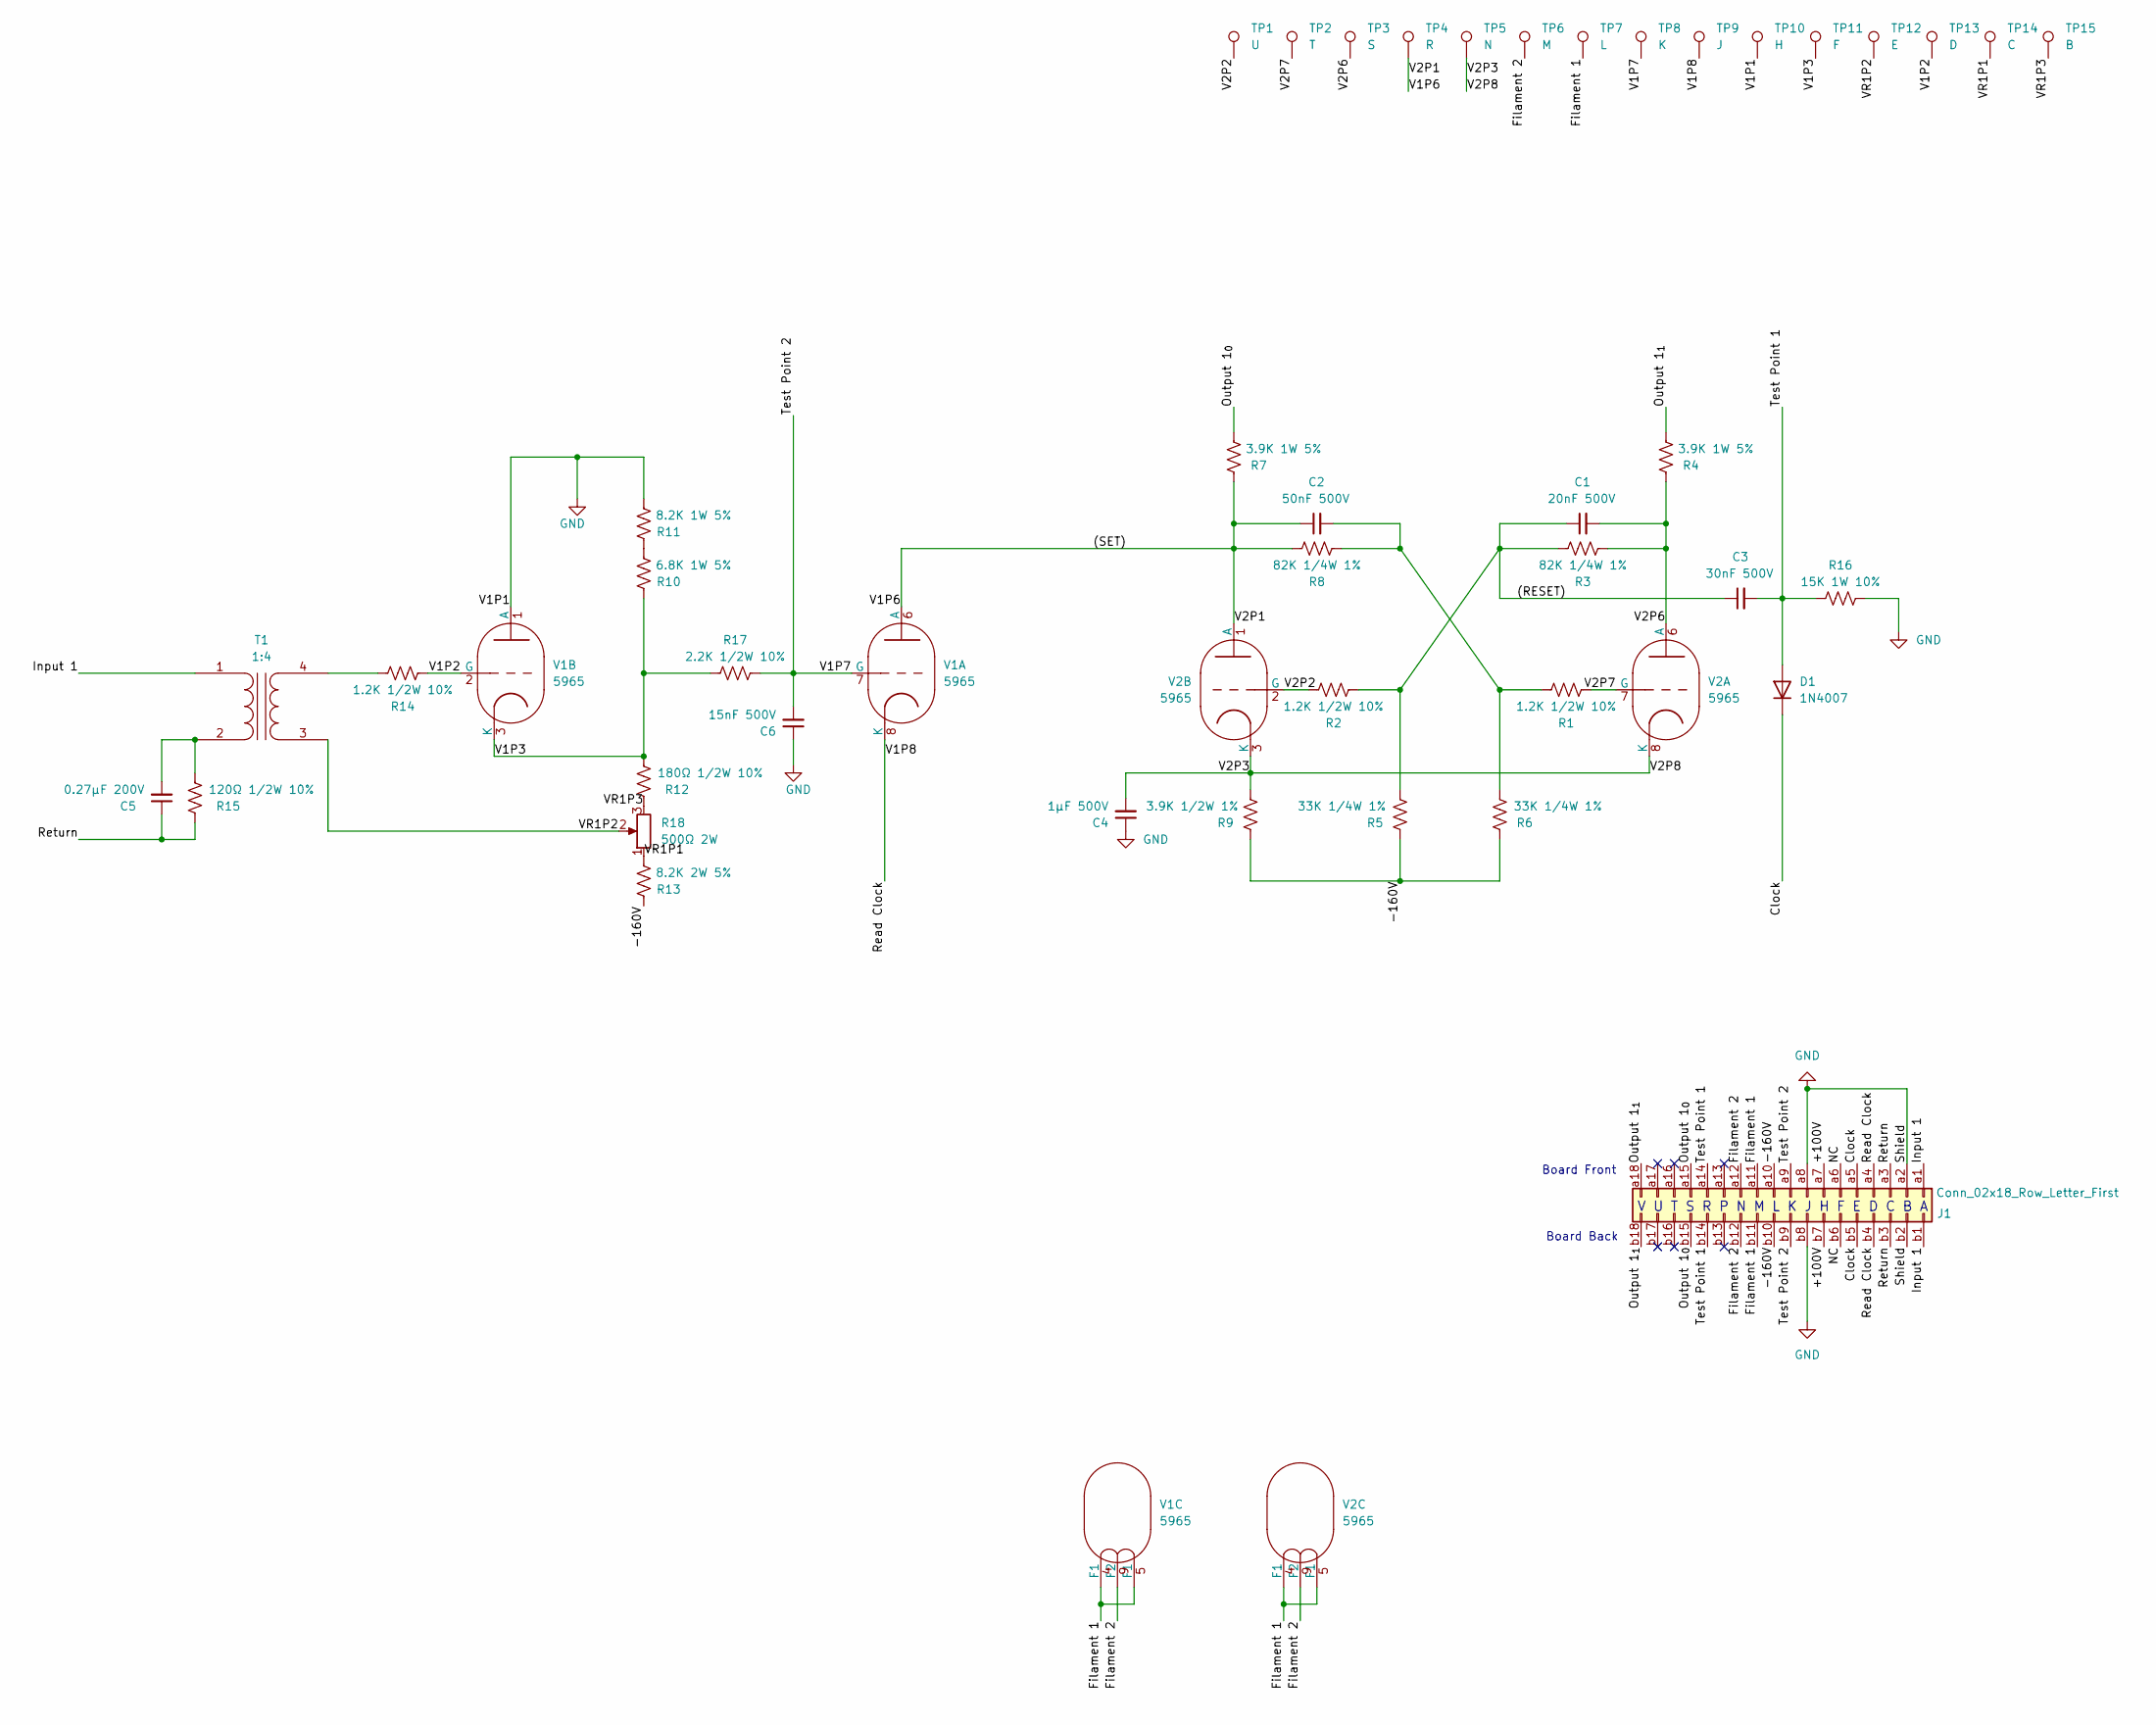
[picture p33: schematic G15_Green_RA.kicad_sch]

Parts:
C1: 20nF 500V; C_Axial_L12.0mm_D6.5mm_P20.00mm_Horizontal
C2: 50nF 500V; C_Axial_L12.0mm_D6.5mm_P20.00mm_Horizontal
C3: 30nF 500V; C_Axial_L12.0mm_D6.5mm_P20.00mm_Horizontal
C4: 1µF 500V; C_Axial_L12.0mm_D6.5mm_P20.00mm_Horizontal
C5: 0.27µF 200V; C_Axial_L22.0mm_D10.5mm_P27.50mm_Horizontal
C6: 15nF 500V; C_Axial_L12.0mm_D6.5mm_P20.00mm_Horizontal
D1: 1N4007; D_DO-35_SOD27_P12.70mm_Horizontal
J1: Conn_02x18_Row_Letter_First; Card_Edge_F_Key
R1, R2, R14: 1.2K 1/2W 10%; R_Axial_DIN0411_L9.9mm_D3.6mm_P15.24mm_Horizontal
R3, R8: 82K 1/4W 1%; R_Axial_DIN0516_L15.5mm_D5.0mm_P20.32mm_Horizontal
R4, R7: 3.9K 1W 5%; R_Axial_DIN0516_L15.5mm_D5.0mm_P20.32mm_Horizontal
R5, R6: 33K 1/4W 1%; R_Axial_DIN0516_L15.5mm_D5.0mm_P20.32mm_Horizontal
R9: 3.9K 1/2W 1%; R_Axial_DIN0617_L17.0mm_D6.0mm_P25.40mm_Horizontal
R10: 6.8K 1W 5%; R_Axial_DIN0516_L15.5mm_D5.0mm_P20.32mm_Horizontal
R11: 8.2K 1W 5%; R_Axial_DIN0516_L15.5mm_D5.0mm_P20.32mm_Horizontal
R12: 180Ω 1/2W 10%; R_Axial_DIN0411_L9.9mm_D3.6mm_P15.24mm_Horizontal
R13: 8.2K 2W 5%; R_Axial_DIN0918_L18.0mm_D9.0mm_P22.86mm_Horizontal
R15: 120Ω 1/2W 10%; R_Axial_DIN0411_L9.9mm_D3.6mm_P15.24mm_Horizontal
R16: 15K 1W 10%; R_Axial_DIN0614_L14.3mm_D5.7mm_P25.40mm_Horizontal
R17: 2.2K 1/2W 10%; R_Axial_DIN0411_L9.9mm_D3.6mm_P15.24mm_Horizontal
R18: 500Ω 2W
T1: 1:4; Transformer_Toroid_Horizontal_D14.0mm_Amidon-T50
TP1: U; TestPoint_Plated_Hole_D2.0mm
TP2: T; TestPoint_Plated_Hole_D2.0mm
TP3: S; TestPoint_Plated_Hole_D2.0mm
TP4: R; TestPoint_Plated_Hole_D2.0mm
TP5: N; TestPoint_Plated_Hole_D2.0mm
TP6: M; TestPoint_Plated_Hole_D2.0mm
TP7: L; TestPoint_Plated_Hole_D2.0mm
TP8: K; TestPoint_Plated_Hole_D2.0mm
TP9: J; TestPoint_Plated_Hole_D2.0mm
TP10: H; TestPoint_Plated_Hole_D2.0mm
TP11: F; TestPoint_Plated_Hole_D2.0mm
TP12: E; TestPoint_Plated_Hole_D2.0mm
TP13: D; TestPoint_Plated_Hole_D2.0mm
TP14: C; TestPoint_Plated_Hole_D2.0mm
TP15: B; TestPoint_Plated_Hole_D2.0mm
V1, V2: 5965

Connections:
/(RESET): C1.1, C3.1, R2.1, R3.2, R5.1
/(SET): C2.1, R7.2, R8.2, TP4.1, V1.6 (A), V2.1 (A)
/+100V: J1.a7, J1.b7
/-160V: J1.a10, J1.b10, R5.2, R6.2, R9.2, R13.2
/Clock: D1.1 (K), J1.a5, J1.b5
/Filament 1: J1.a11, J1.b11, TP7.1, V1.4 (F1), V1.5 (F1), V2.4 (F1), V2.5 (F1)
/Filament 2: J1.a12, J1.b12, TP6.1, V1.9 (F2), V2.9 (F2)
/Input 1: J1.a1, J1.b1, T1.1 (AA)
/Output 1_{0}: J1.a15, J1.b15, R7.1
/Output 1_{1}: J1.a18, J1.b18, R4.1
/Read Clock: J1.a4, J1.b4, TP9.1, V1.8 (K)
/Return: C5.1, J1.a3, J1.b3, R15.2
/Test Point 1: C3.2, D1.2 (A), J1.a14, J1.b14, R16.1
/V1P2: R14.1, TP13.1, V1.2 (G)
/V1P3: R10.2, R12.1, R17.1, TP11.1, V1.3 (K)
/V1P7: C6.2, J1.a9, J1.b9, R17.2, TP8.1, V1.7 (G)
/V2P2: R2.2, TP1.1, V2.2 (G)
/V2P3: C4.2, R9.1, TP5.1, V2.3 (K), V2.8 (K)
/V2P6: C1.2, R3.1, R4.2, TP3.1, V2.6 (A)
/V2P7: R1.1, TP2.1, V2.7 (G)
/VR1P1: R13.1, R18.1, TP14.1
/VR1P2: R18.2, T1.3 (SA), TP12.1
/VR1P3: R12.2, R18.3, TP15.1
GND: C4.1, C6.1, J1.a2, J1.a8, J1.b2, J1.b8, R11.1, R16.2, TP10.1, V1.1 (A)
unnamed: C2.2, R1.2, R6.1, R8.1
unnamed: C5.2, R15.1, T1.2 (AB)
unnamed: R10.1, R11.2
unnamed: R14.2, T1.4 (SB)

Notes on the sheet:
Board Back
Board Front
V U T S R P N M L K J H F E D C B A

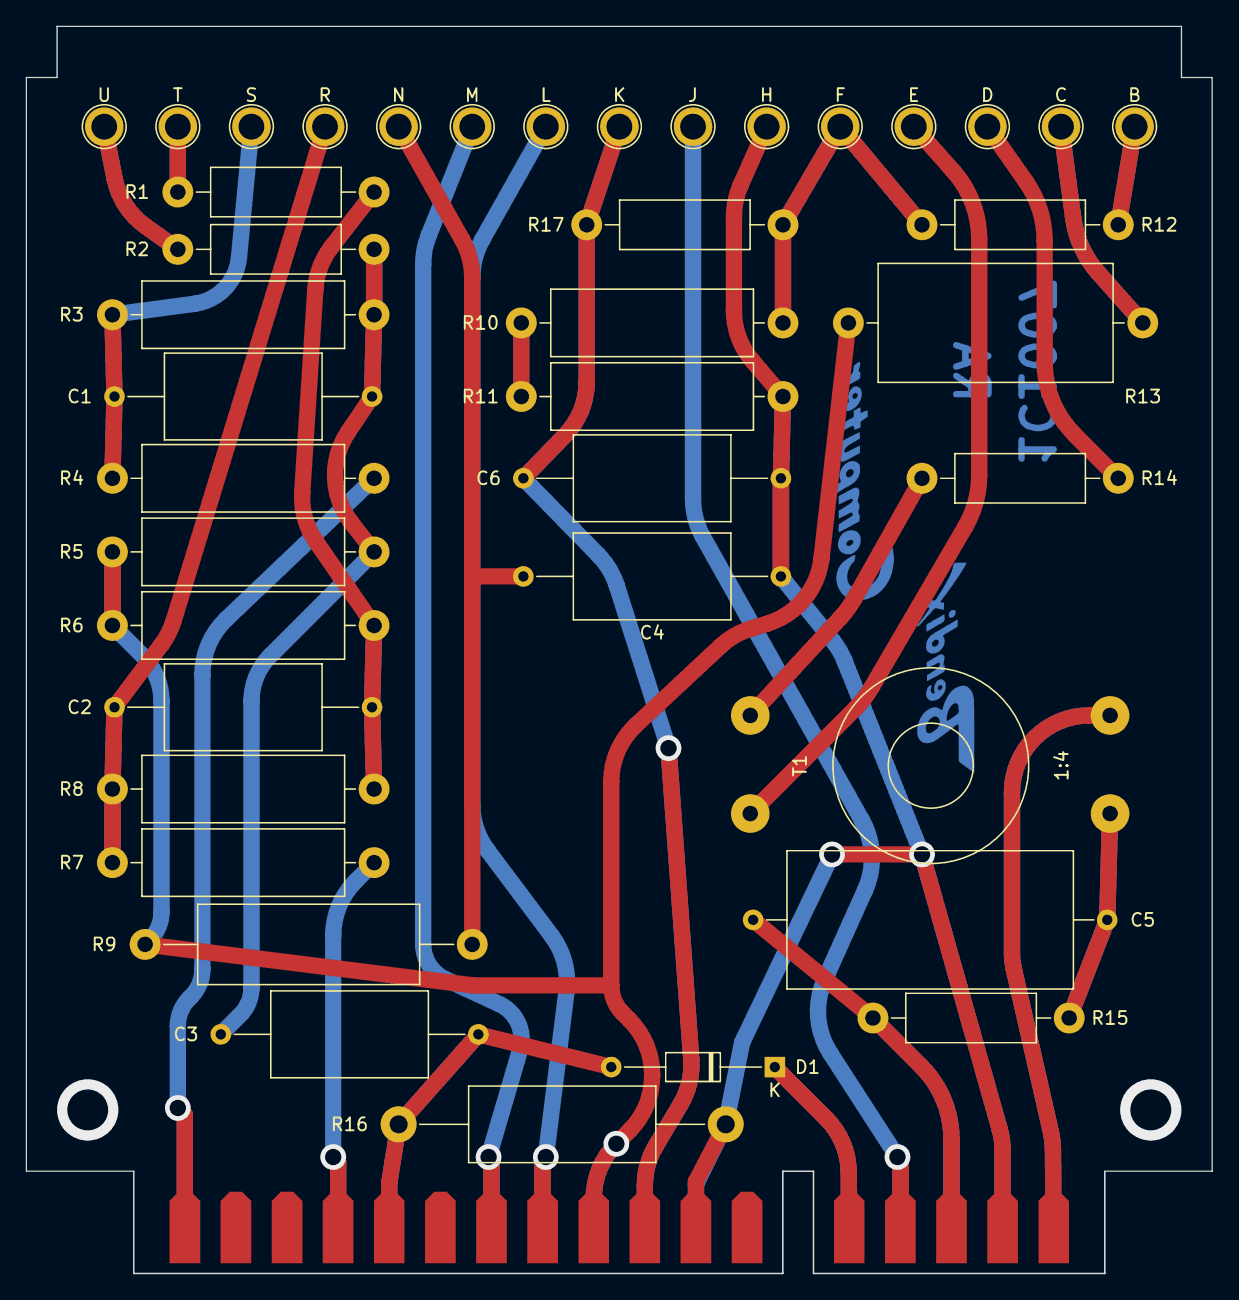
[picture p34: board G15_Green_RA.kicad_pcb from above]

Board: 2 copper layers, 92.1 x 96.8 mm, 41 parts (0 on the bottom side), 28 nets.

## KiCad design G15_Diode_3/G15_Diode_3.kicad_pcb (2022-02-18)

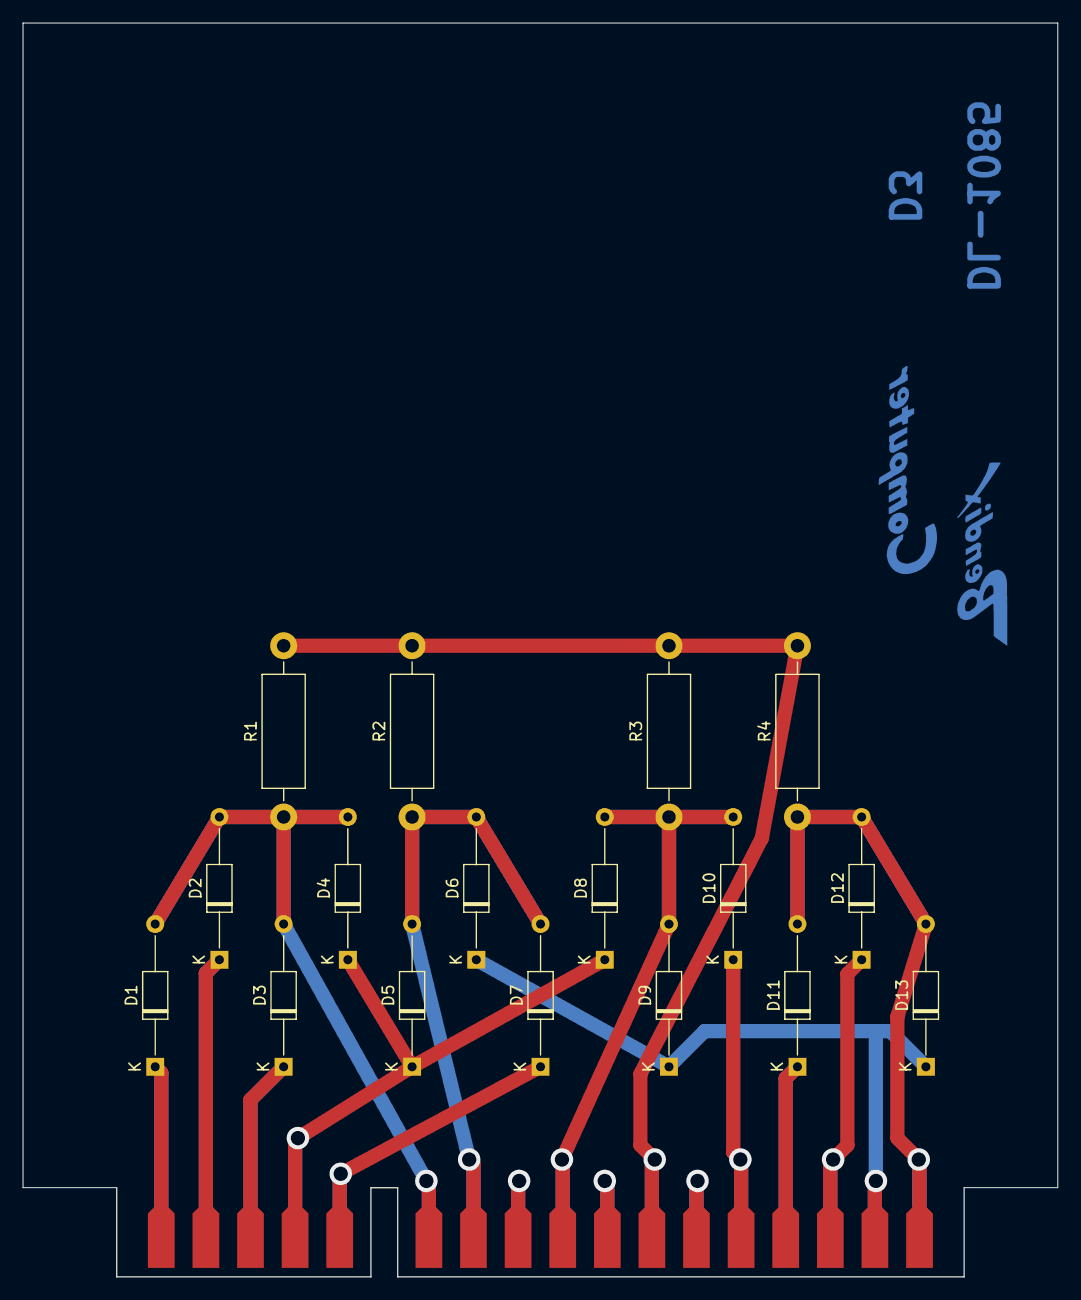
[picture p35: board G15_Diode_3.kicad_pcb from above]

Board: 2 copper layers, 92.1 x 111.6 mm, 18 parts (0 on the bottom side), 17 nets.

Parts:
D1, D2, D3, D4, D5, D6, D7, D8, D9, D10, D11, D12, D13: 1N4007; D_DO-35_SOD27_P12.70mm_Horizontal
J1: Conn_02x18_Row_Letter_First; Card_Edge_P_Key
R1, R2, R3, R4: 110K 1/2W 5%; R_Axial_DIN0411_L9.9mm_D3.6mm_P15.24mm_Horizontal

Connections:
/+100V: J1.a7, J1.b7, R1.2, R2.2, R3.2, R4.2
/C_{1}: D1.1 (K), J1.a18, J1.b18
/C_{2}: D2.1 (K), J1.a17, J1.b17
/C_{3}: D3.1 (K), J1.a16, J1.b16
/C_{4,5,8}: D4.1 (K), D5.1 (K), D8.1 (K), J1.a15, J1.b15
/C_{6,9,13}: D6.1 (K), D9.1 (K), D13.1 (K), J1.a2, J1.b2
/C_{7}: D7.1 (K), J1.a14, J1.b14
/C_{10}: D10.1 (K), J1.a5, J1.b5
/C_{11}: D11.1 (K), J1.a4, J1.b4
/C_{12}: D12.1 (K), J1.a3, J1.b3
/NC1: J1.a10, J1.b10
/NC2: J1.a8, J1.b8
/NC3: J1.a6, J1.b6
/P_{1,2,3,4}: D1.2 (A), D2.2 (A), D3.2 (A), D4.2 (A), J1.a12, J1.b12, R1.1
/P_{5,6,7}: D5.2 (A), D6.2 (A), D7.2 (A), J1.a11, J1.b11, R2.1
/P_{8,9,10}: D8.2 (A), D9.2 (A), D10.2 (A), J1.a9, J1.b9, R3.1
/P_{11,12,13}: D11.2 (A), D12.2 (A), D13.2 (A), J1.a1, J1.b1, R4.1

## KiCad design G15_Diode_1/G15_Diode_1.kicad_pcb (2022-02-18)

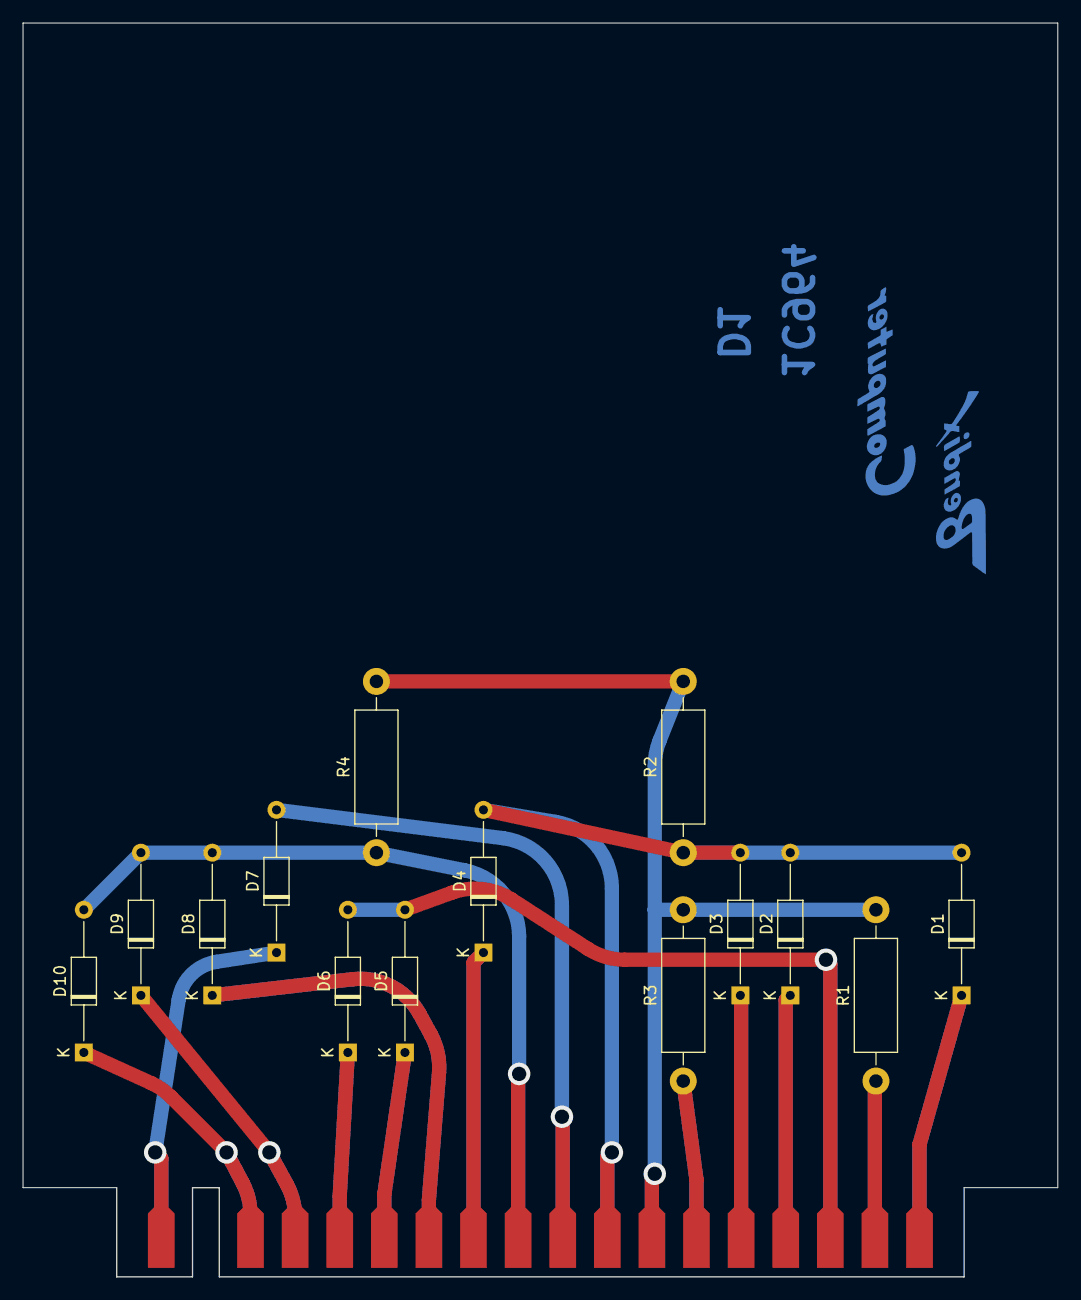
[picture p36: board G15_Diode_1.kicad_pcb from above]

Board: 2 copper layers, 92.1 x 111.6 mm, 15 parts (0 on the bottom side), 17 nets.

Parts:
D1, D2, D3, D4, D5, D6, D7, D8, D9, D10: 1N4007; D_DO-35_SOD27_P12.70mm_Horizontal
J1: Conn_02x18_Row_Letter_First; Card_Edge_U_Key
R1, R2, R4: 110K 1/2W 5%; R_Axial_DIN0411_L9.9mm_D3.6mm_P15.24mm_Horizontal
R3: 150K 1/2W 5%; R_Axial_DIN0411_L9.9mm_D3.6mm_P15.24mm_Horizontal

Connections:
/110K to B+: J1.a2, J1.b2, R1.1
/150K to B+: J1.a6, J1.b6, R3.1
/+100V: J1.a7, J1.b7, R1.2, R2.2, R3.2, R4.2
/C_{1}: D1.1 (K), J1.a1, J1.b1
/C_{2}: D2.1 (K), J1.a4, J1.b4
/C_{3}: D3.1 (K), J1.a5, J1.b5
/C_{4}: D4.1 (K), J1.a11, J1.b11
/C_{5}: D5.1 (K), J1.a13, J1.b13
/C_{6}: D6.1 (K), J1.a14, J1.b14
/C_{7}: D7.1 (K), J1.a18, J1.b18
/C_{8}: D8.1 (K), J1.a12, J1.b12
/C_{9}: D9.1 (K), J1.a15, J1.b15
/C_{10}: D10.1 (K), J1.a16, J1.b16
/P_{1,2,3,4}: D1.2 (A), D2.2 (A), D3.2 (A), D4.2 (A), J1.a8, J1.b8, R2.1
/P_{5,6}: D5.2 (A), D6.2 (A), J1.a3, J1.b3
/P_{7}: D7.2 (A), J1.a9, J1.b9
/P_{8,9,10}: D8.2 (A), D9.2 (A), D10.2 (A), J1.a10, J1.b10, R4.1

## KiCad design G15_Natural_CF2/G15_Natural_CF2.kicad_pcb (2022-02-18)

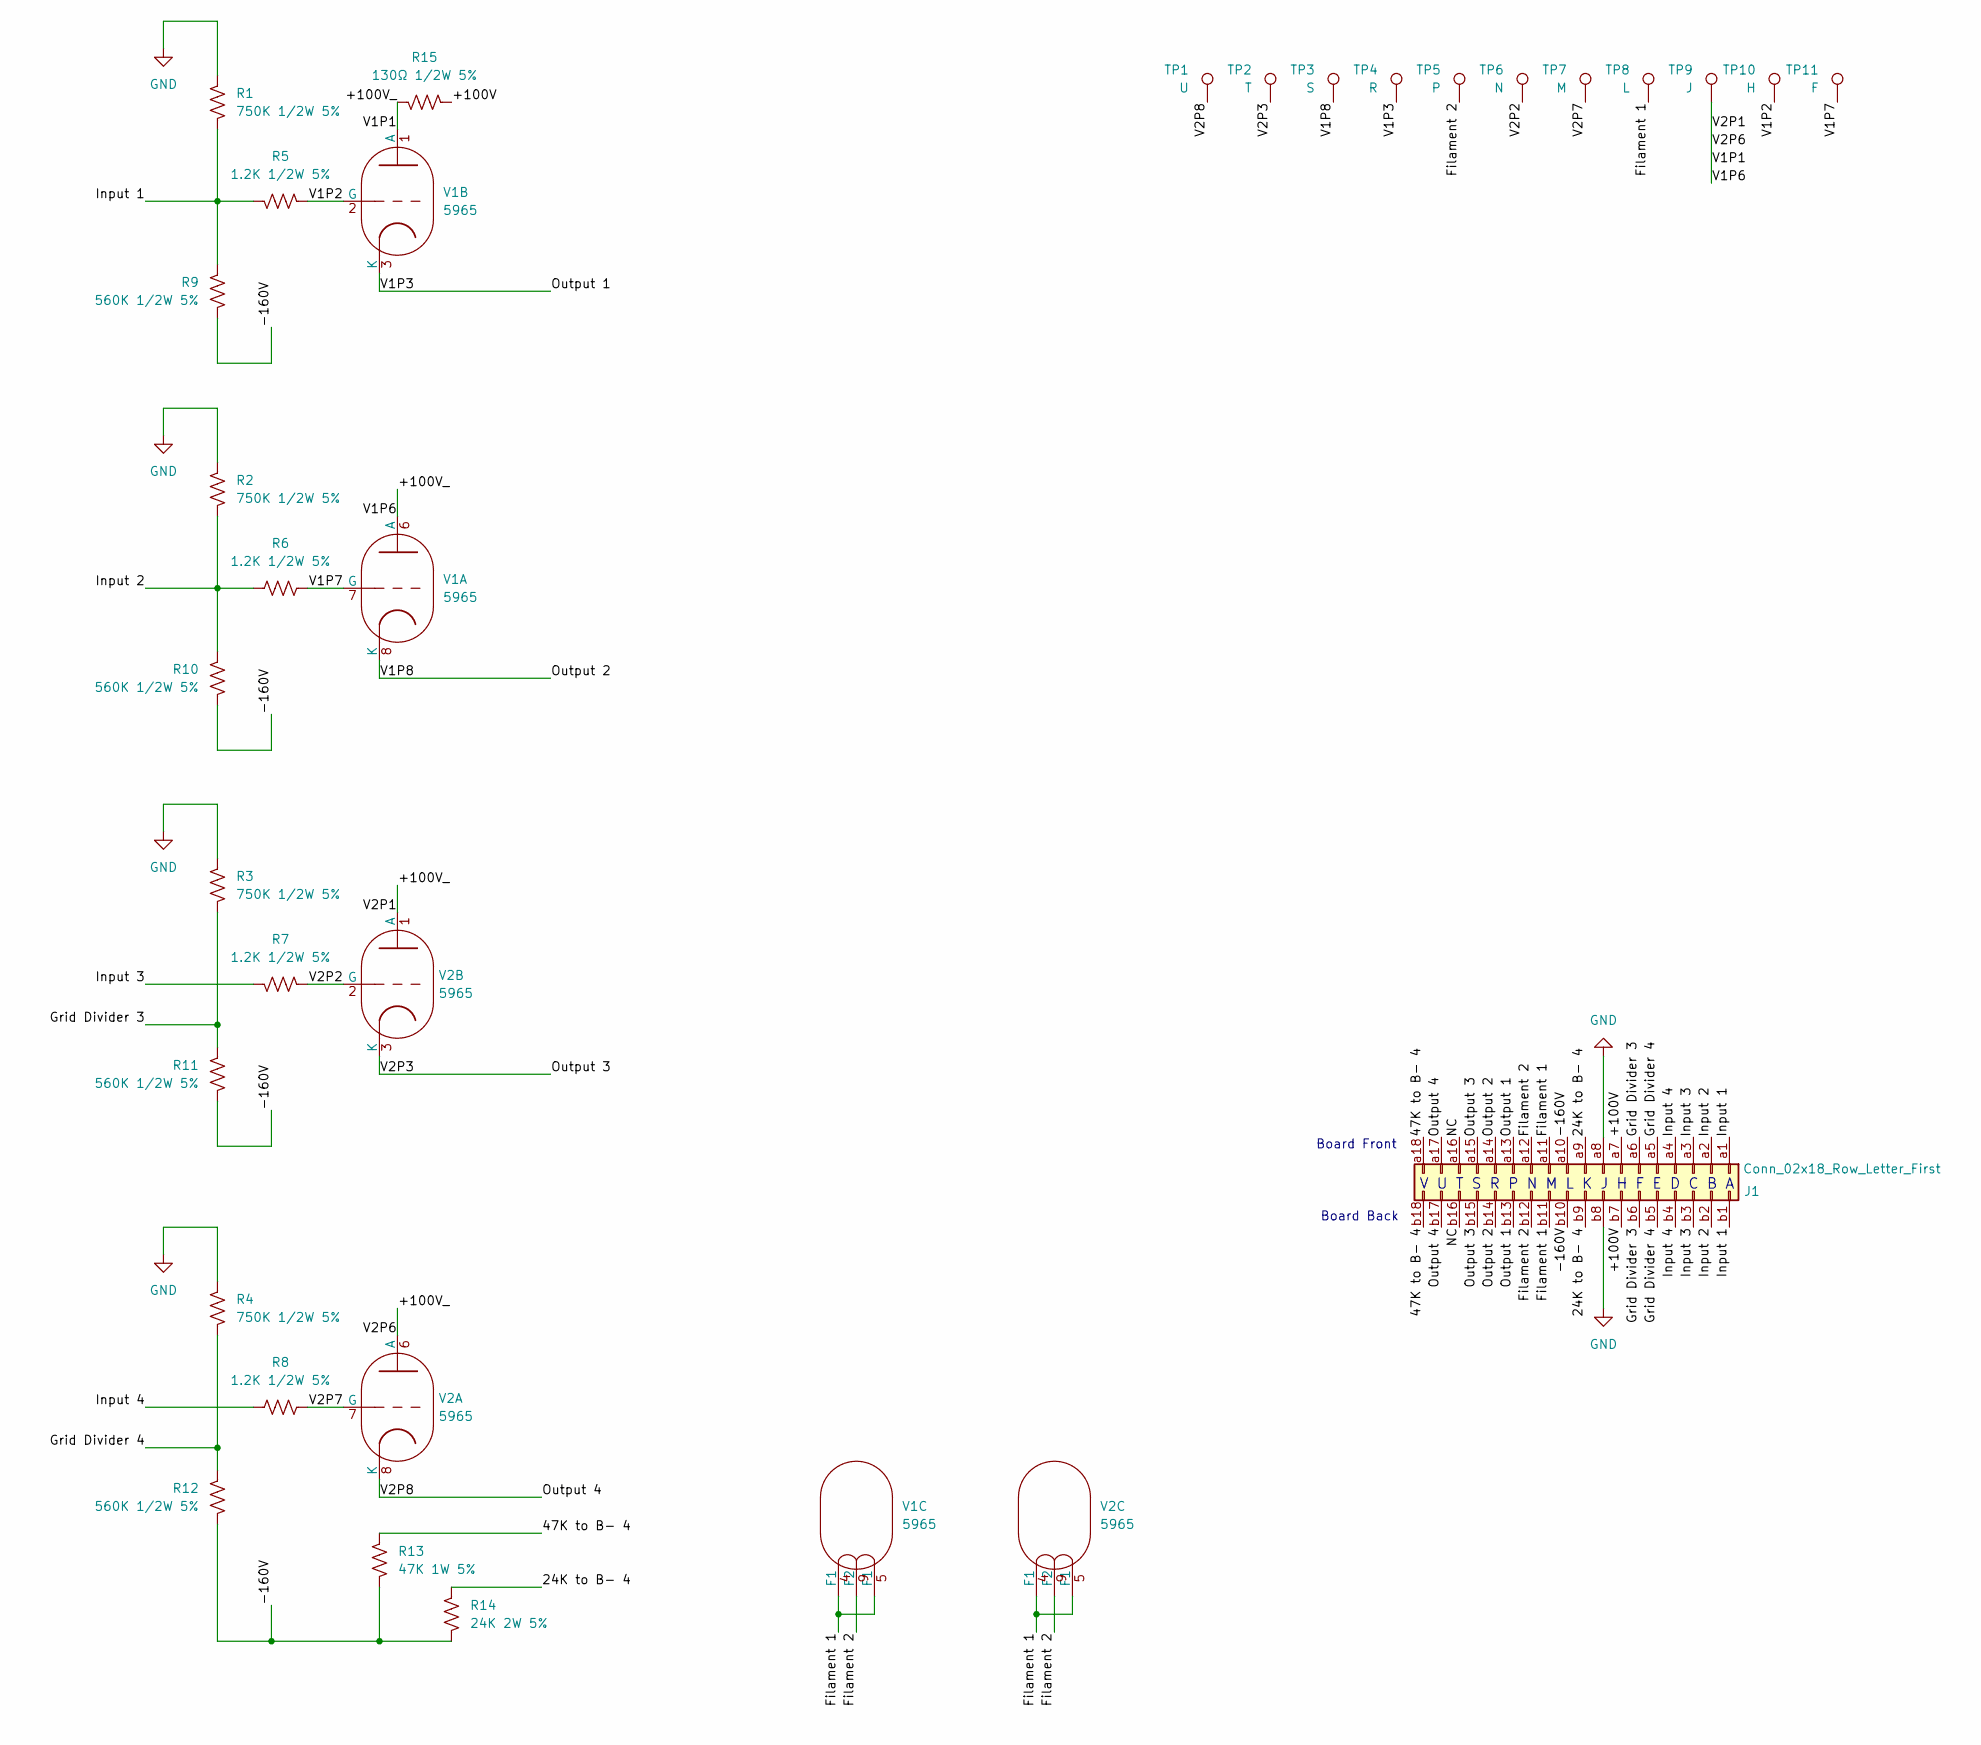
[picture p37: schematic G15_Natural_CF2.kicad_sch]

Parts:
J1: Conn_02x18_Row_Letter_First; Card_Edge_T_Key
R1, R2, R3, R4: 750K 1/2W 5%; R_Axial_DIN0309_L9.0mm_D3.2mm_P15.24mm_Horizontal
R5, R6, R7, R8: 1.2K 1/2W 5%; R_Axial_DIN0309_L9.0mm_D3.2mm_P15.24mm_Horizontal
R9, R10, R11, R12: 560K 1/2W 5%; R_Axial_DIN0309_L9.0mm_D3.2mm_P15.24mm_Horizontal
R13: 47K 1W 5%; R_Axial_DIN0516_L15.5mm_D5.0mm_P20.32mm_Horizontal
R14: 24K 2W 5%; R_Axial_DIN0918_L18.0mm_D9.0mm_P25.40mm_Horizontal
R15: 130Ω 1/2W 5%; R_Axial_DIN0309_L9.0mm_D3.2mm_P15.24mm_Horizontal
TP1: U; TestPoint_Plated_Hole_D2.0mm
TP2: T; TestPoint_Plated_Hole_D2.0mm
TP3: S; TestPoint_Plated_Hole_D2.0mm
TP4: R; TestPoint_Plated_Hole_D2.0mm
TP5: P; TestPoint_Plated_Hole_D2.0mm
TP6: N; TestPoint_Plated_Hole_D2.0mm
TP7: M; TestPoint_Plated_Hole_D2.0mm
TP8: L; TestPoint_Plated_Hole_D2.0mm
TP9: J; TestPoint_Plated_Hole_D2.0mm
TP10: H; TestPoint_Plated_Hole_D2.0mm
TP11: F; TestPoint_Plated_Hole_D2.0mm
V1, V2: 5965

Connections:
/24K to B- 4: J1.a9, J1.b9, R14.1
/47K to B- 4: J1.a18, J1.b18, R13.1
/+100V: J1.a7, J1.b7, R15.2
/+100V_: R15.1, TP9.1, V1.1 (A), V1.6 (A), V2.1 (A), V2.6 (A)
/-160V: J1.a10, J1.b10, R9.1, R10.1, R11.1, R12.1, R13.2, R14.2
/Filament 1: J1.a11, J1.b11, TP8.1, V1.4 (F1), V1.5 (F1), V2.4 (F1), V2.5 (F1)
/Filament 2: J1.a12, J1.b12, TP5.1, V1.9 (F2), V2.9 (F2)
/Grid Divider 3: J1.a6, J1.b6, R3.2, R11.2
/Grid Divider 4: J1.a5, J1.b5, R4.2, R12.2
/Input 1: J1.a1, J1.b1, R1.2, R5.1, R9.2
/Input 2: J1.a2, J1.b2, R2.2, R6.2, R10.2
/Input 3: J1.a3, J1.b3, R7.1
/Input 4: J1.a4, J1.b4, R8.2
/Output 1: J1.a13, J1.b13, TP4.1, V1.3 (K)
/Output 2: J1.a14, J1.b14, TP3.1, V1.8 (K)
/Output 3: J1.a15, J1.b15, TP2.1, V2.3 (K)
/Output 4: J1.a17, J1.b17, TP1.1, V2.8 (K)
/V1P2: R5.2, TP10.1, V1.2 (G)
/V1P7: R6.1, TP11.1, V1.7 (G)
/V2P2: R7.2, TP6.1, V2.2 (G)
/V2P7: R8.1, TP7.1, V2.7 (G)
GND: J1.a8, J1.b8, R1.1, R2.1, R3.1, R4.1

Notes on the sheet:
Board Back
Board Front
V U T S R P N M L K J H F E D C B A

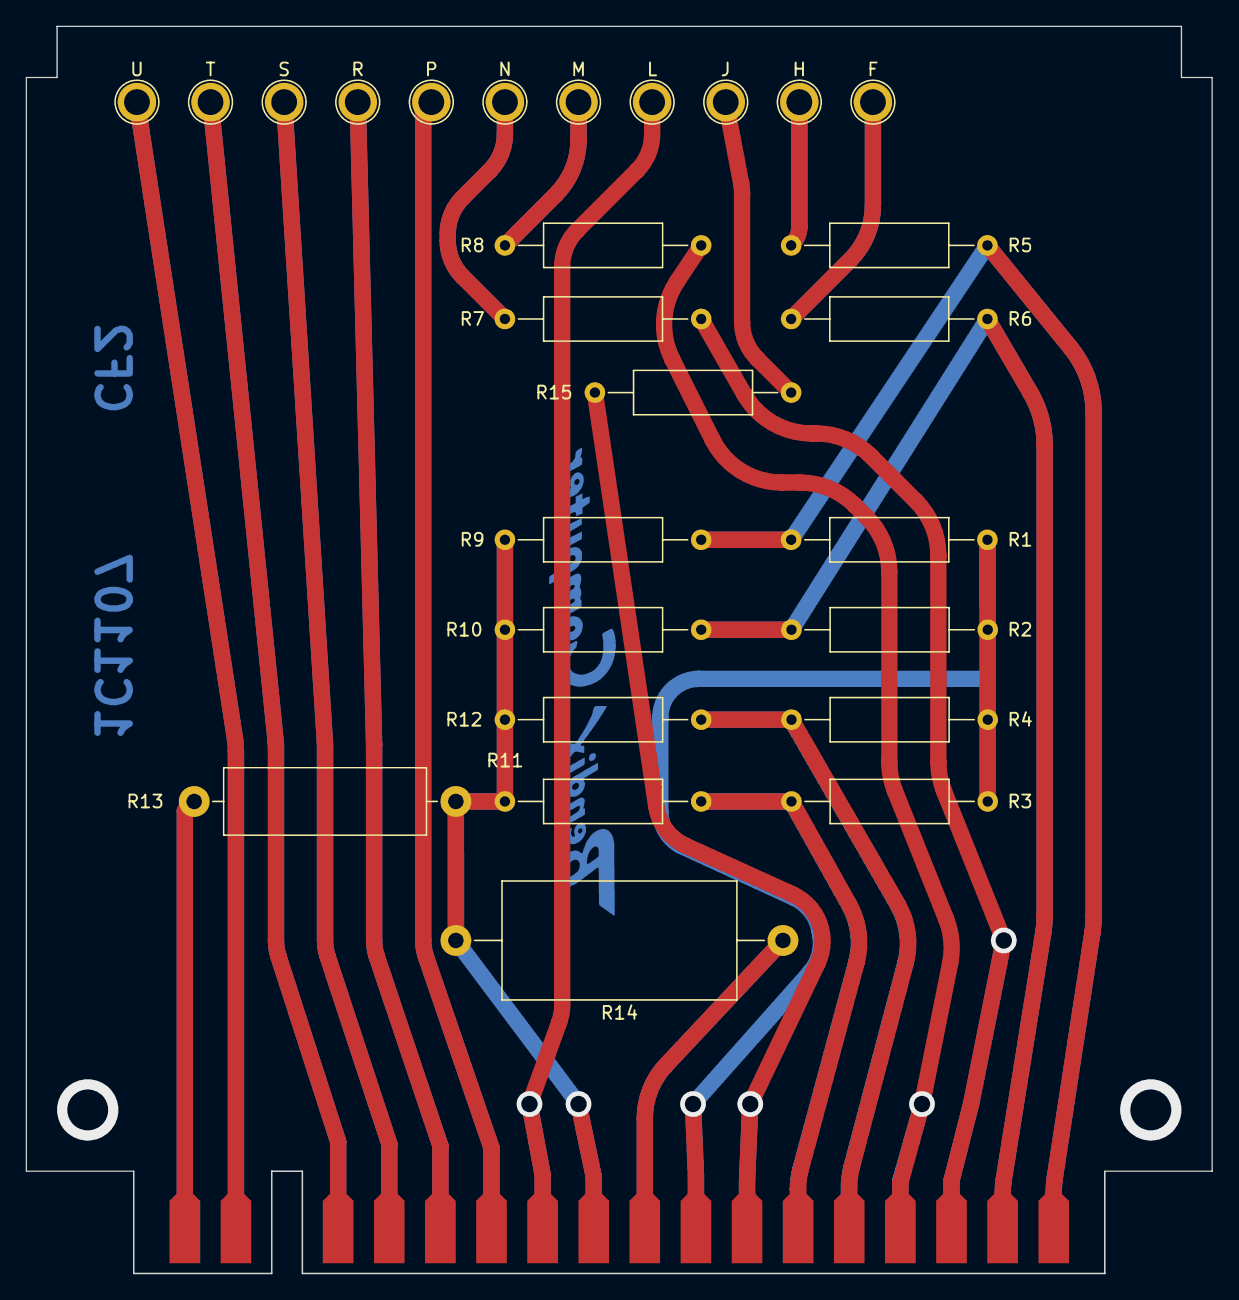
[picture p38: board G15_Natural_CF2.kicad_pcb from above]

Board: 2 copper layers, 92.1 x 96.8 mm, 27 parts (0 on the bottom side), 22 nets.

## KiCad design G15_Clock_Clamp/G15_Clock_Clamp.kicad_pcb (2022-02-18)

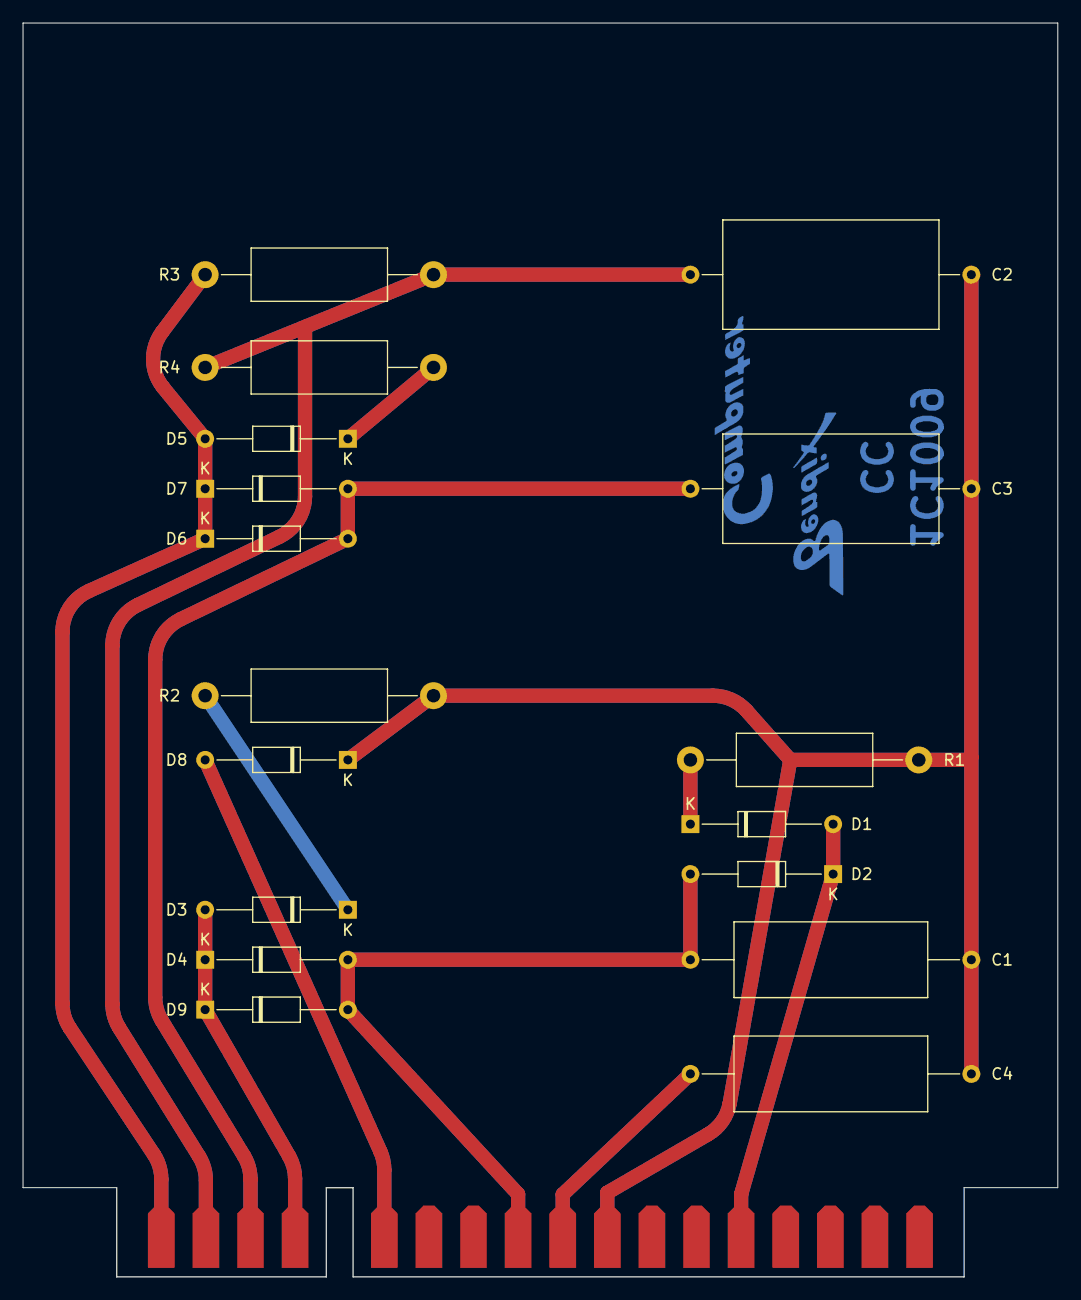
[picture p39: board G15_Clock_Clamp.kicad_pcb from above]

Board: 2 copper layers, 92.1 x 111.6 mm, 18 parts (0 on the bottom side), 12 nets.

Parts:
C1, C4: 4µF; C_Axial_L17.0mm_D6.5mm_P25.00mm_Horizontal
C2, C3: 0.1µF 200V; C_Axial_L19.0mm_D9.5mm_P25.00mm_Horizontal
D1, D3, D5: 1N4007; D_DO-35_SOD27_P12.70mm_Horizontal
D2, D4, D6, D7, D8, D9: 1N4007_{2}; D_DO-35_SOD27_P12.70mm_Horizontal
J1: Conn_02x18_Row_Letter_First; Card_Edge_R_Key
R1, R2, R4: 33Ω 1W 5%; R_Axial_DIN0414_L11.9mm_D4.5mm_P20.32mm_Horizontal
R3: 390Ω 1W 5%; R_Axial_DIN0414_L11.9mm_D4.5mm_P20.32mm_Horizontal

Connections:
/*-25V: C2.1, J1.a17, J1.b17, R3.1, R4.1
/*-75V: C3.1, D6.2 (A), D7.2 (A), J1.a16, J1.b16
/-13V: C1.1, D2.2 (A), D4.2 (A), D9.2 (A), J1.a10, J1.b10
/-20V: C4.1, J1.a9, J1.b9
/Clock Pulse: D1.2 (A), D2.1 (K), J1.a5, J1.b5
/Read Pulse: D5.2 (A), D6.1 (K), D7.1 (K), J1.a18, J1.b18, R3.2
/Shift Pulse: D3.2 (A), D4.1 (K), D9.1 (K), J1.a15, J1.b15
/Write Pulse: D8.2 (A), J1.a13, J1.b13
GND: C1.2, C2.2, C3.2, C4.2, D8.1 (K), J1.a8, J1.b8, R1.1, R2.1
unnamed: D1.1 (K), R1.2
unnamed: D3.1 (K), R2.2
unnamed: D5.1 (K), R4.2

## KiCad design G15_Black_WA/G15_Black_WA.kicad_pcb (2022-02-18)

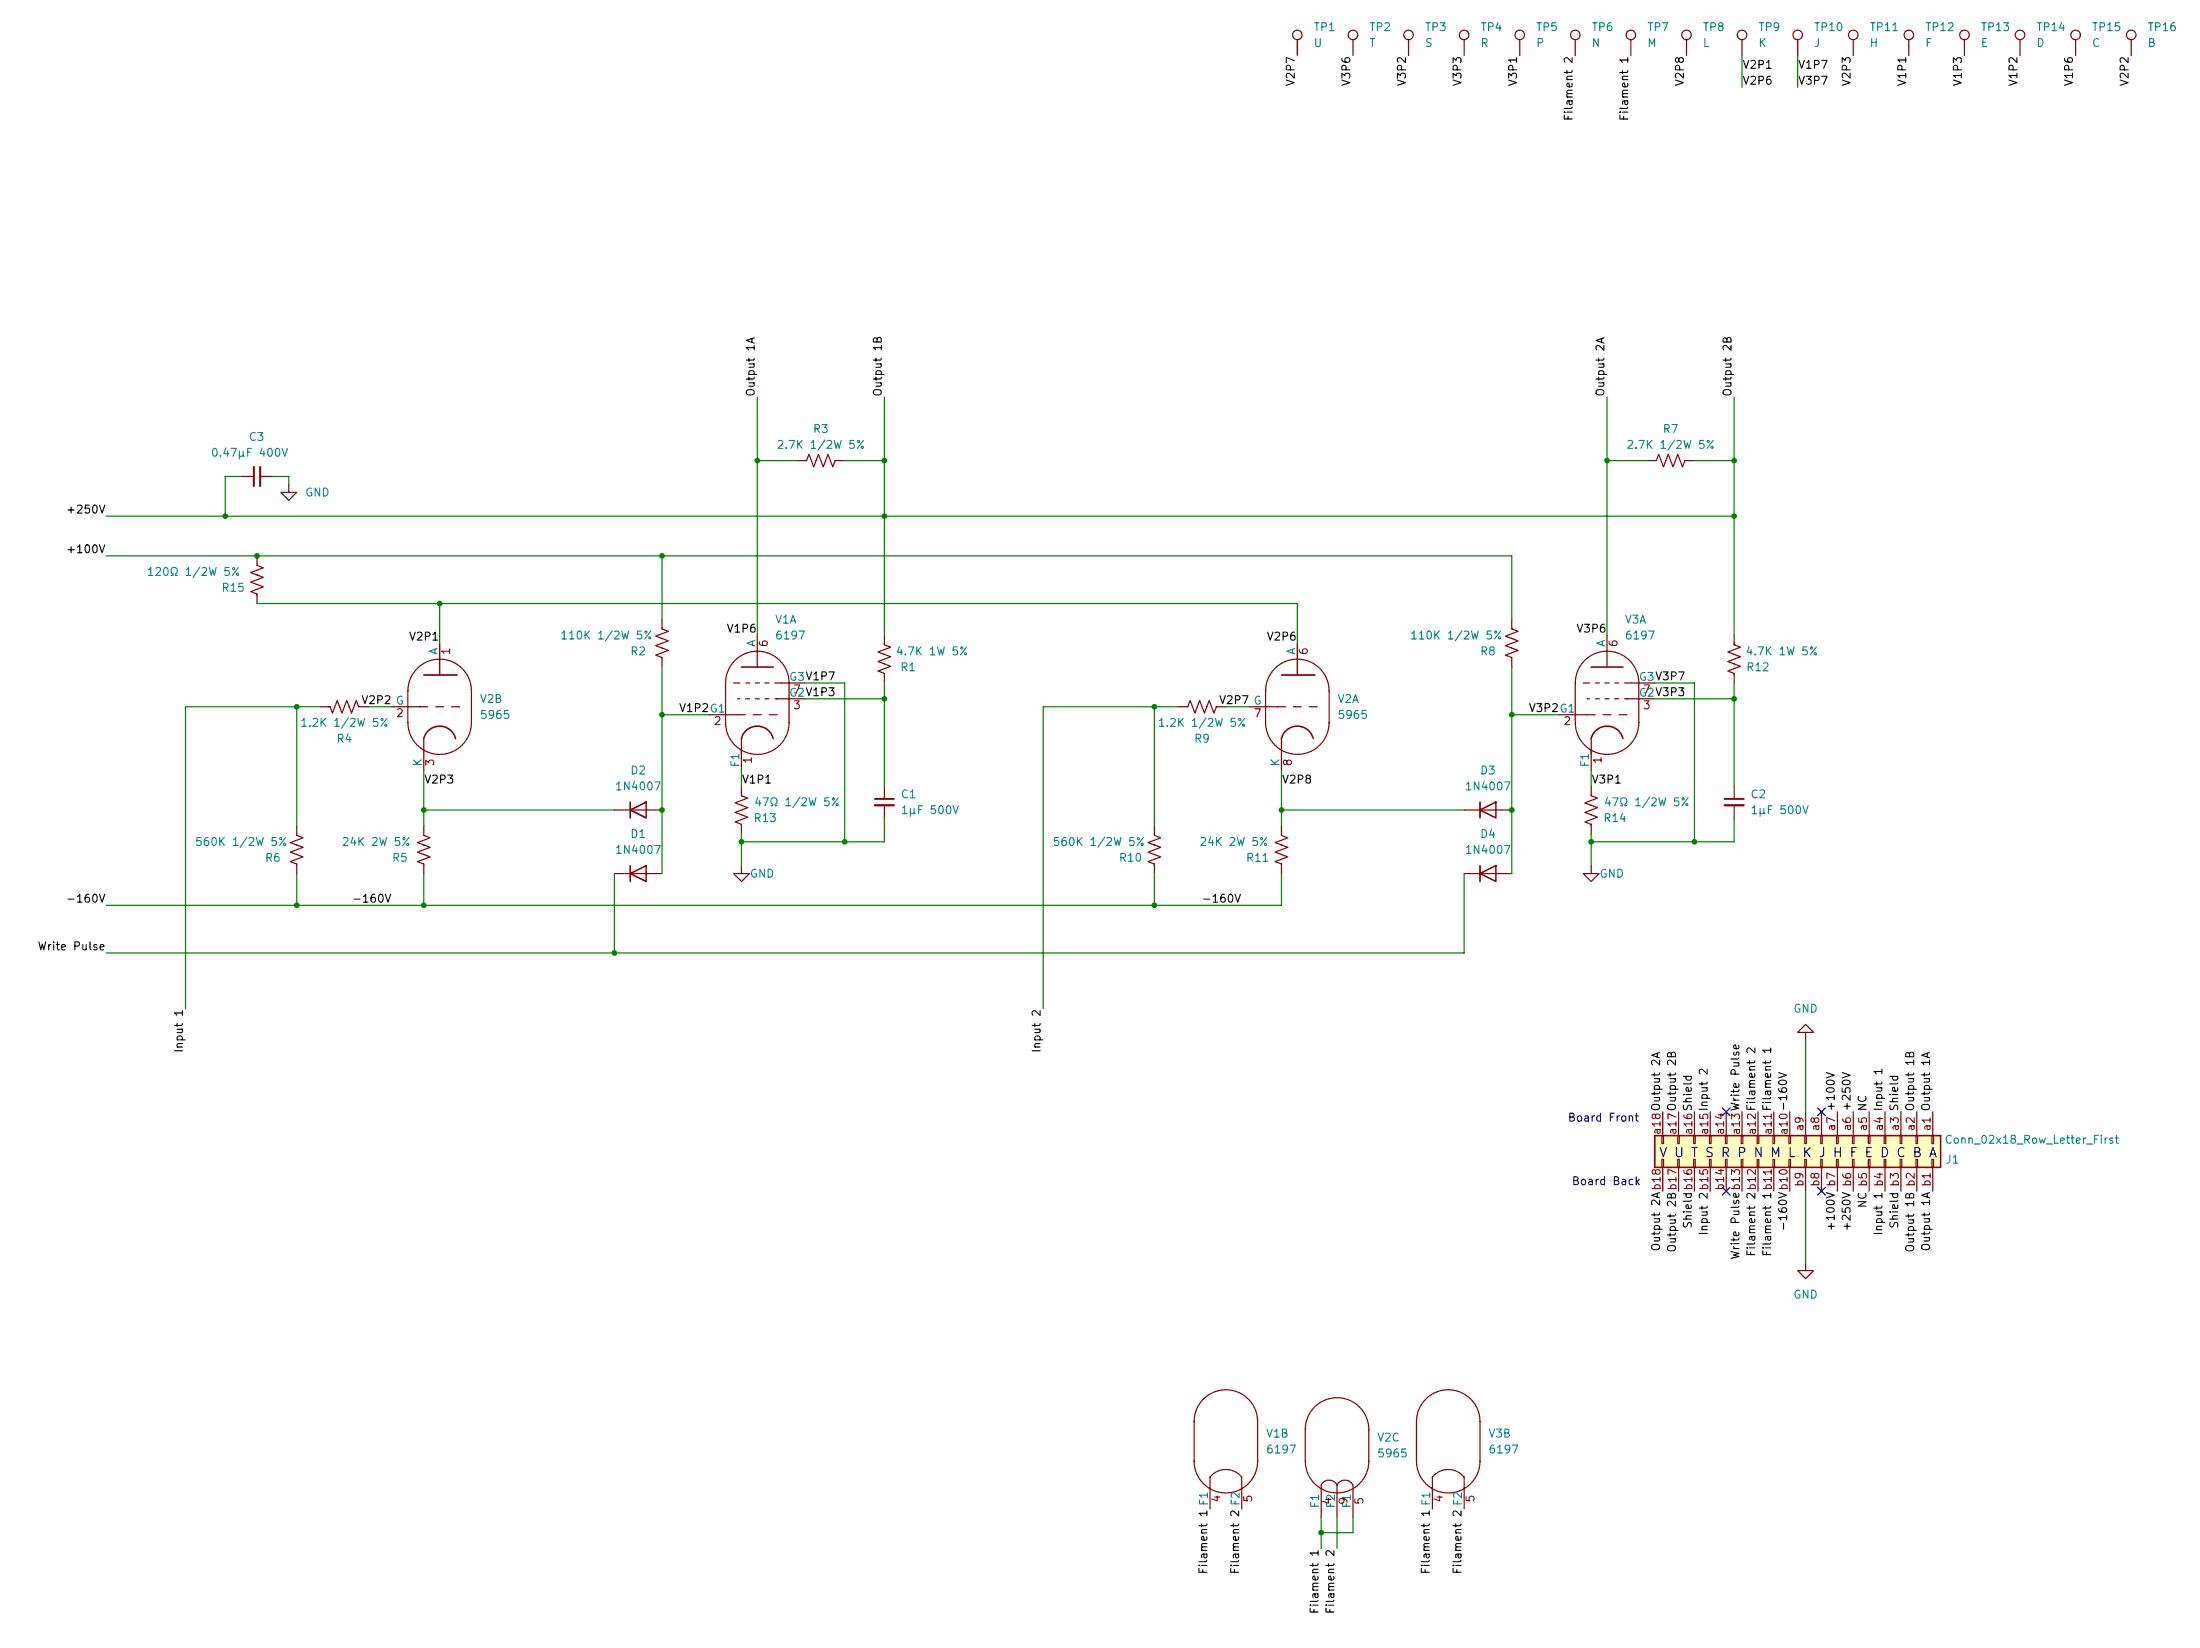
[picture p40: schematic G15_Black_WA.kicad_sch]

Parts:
C1, C2: 1µF 500V; C_Axial_L12.0mm_D6.5mm_P20.00mm_Horizontal
C3: 0.47µF 400V; C_Axial_L22.0mm_D10.5mm_P27.50mm_Horizontal
D1, D2, D3, D4: 1N4007; D_DO-35_SOD27_P12.70mm_Horizontal
J1: Conn_02x18_Row_Letter_First; Card_Edge_E_Key
R1, R12: 4.7K 1W 5%; R_Axial_DIN0516_L15.5mm_D5.0mm_P20.32mm_Horizontal
R2, R8: 110K 1/2W 5%; R_Axial_DIN0411_L9.9mm_D3.6mm_P20.32mm_Horizontal
R3, R7: 2.7K 1/2W 5%; R_Axial_DIN0516_L15.5mm_D5.0mm_P20.32mm_Horizontal
R4, R9: 1.2K 1/2W 5%; R_Axial_DIN0411_L9.9mm_D3.6mm_P15.24mm_Horizontal
R5, R11: 24K 2W 5%; R_Axial_DIN0617_L17.0mm_D6.0mm_P25.40mm_Horizontal
R6, R10: 560K 1/2W 5%; R_Axial_DIN0411_L9.9mm_D3.6mm_P15.24mm_Horizontal
R13, R14: 47Ω 1/2W 5%; R_Axial_DIN0411_L9.9mm_D3.6mm_P15.24mm_Horizontal
R15: 120Ω 1/2W 5%; R_Axial_DIN0411_L9.9mm_D3.6mm_P15.24mm_Horizontal
TP1: U; TestPoint_Plated_Hole_D2.0mm
TP2: T; TestPoint_Plated_Hole_D2.0mm
TP3: S; TestPoint_Plated_Hole_D2.0mm
TP4: R; TestPoint_Plated_Hole_D2.0mm
TP5: P; TestPoint_Plated_Hole_D2.0mm
TP6: N; TestPoint_Plated_Hole_D2.0mm
TP7: M; TestPoint_Plated_Hole_D2.0mm
TP8: L; TestPoint_Plated_Hole_D2.0mm
TP9: K; TestPoint_Plated_Hole_D2.0mm
TP10: J; TestPoint_Plated_Hole_D2.0mm
TP11: H; TestPoint_Plated_Hole_D2.0mm
TP12: F; TestPoint_Plated_Hole_D2.0mm
TP13: E; TestPoint_Plated_Hole_D2.0mm
TP14: D; TestPoint_Plated_Hole_D2.0mm
TP15: C; TestPoint_Plated_Hole_D2.0mm
TP16: B; TestPoint_Plated_Hole_D2.0mm
V1, V3: 6197
V2: 5965

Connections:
/+100V: J1.a7, J1.b7, R2.2, R8.2, R15.2
/+250V: C3.1, J1.a2, J1.a6, J1.a17, J1.b2, J1.b6, J1.b17, R1.2, R3.2, R7.2, R12.2
/-160V: J1.a10, J1.b10, R5.1, R6.1, R10.1, R11.1
/Filament 1: J1.a11, J1.b11, TP7.1, V1.4 (F1), V2.4 (F1), V2.5 (F1), V3.4 (F1)
/Filament 2: J1.a12, J1.b12, TP6.1, V1.5 (F2), V2.9 (F2), V3.5 (F2)
/Input 1: J1.a4, J1.b4, R4.1, R6.2
/Input 2: J1.a15, J1.b15, R9.2, R10.2
/Output 1A: J1.a1, J1.b1, R3.1, TP15.1, V1.6 (S)
/Output 2A: J1.a18, J1.b18, R7.1, TP2.1, V3.6 (S)
/Shield: J1.a3, J1.a16, J1.b3, J1.b16
/V1P1: R13.2, TP12.1, V1.1 (F1)
/V1P2: D1.2 (A), D2.2 (A), R2.1, TP14.1, V1.2 (G1)
/V1P3: C1.1, R1.1, TP13.1, V1.3 (F1)
/V2P1: R15.1, TP9.1, V2.1 (A), V2.6 (A)
/V2P2: R4.2, TP16.1, V2.2 (G)
/V2P3: D2.1 (K), R5.2, TP11.1, V2.3 (K)
/V2P7: R9.1, TP1.1, V2.7 (G)
/V2P8: D3.1 (K), R11.2, TP8.1, V2.8 (K)
/V3P1: R14.2, TP5.1, V3.1 (F1)
/V3P2: D3.2 (A), D4.2 (A), R8.1, TP3.1, V3.2 (G1)
/V3P3: C2.1, R12.1, TP4.1, V3.3 (F1)
/Write Pulse: D1.1 (K), D4.1 (K), J1.a13, J1.b13
GND: C1.2, C2.2, C3.2, J1.a9, J1.b9, R13.1, R14.1, TP10.1, V1.7 (A), V3.7 (A)

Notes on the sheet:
Board Back
Board Front
V U T S R P N M L K J H F E D C B A

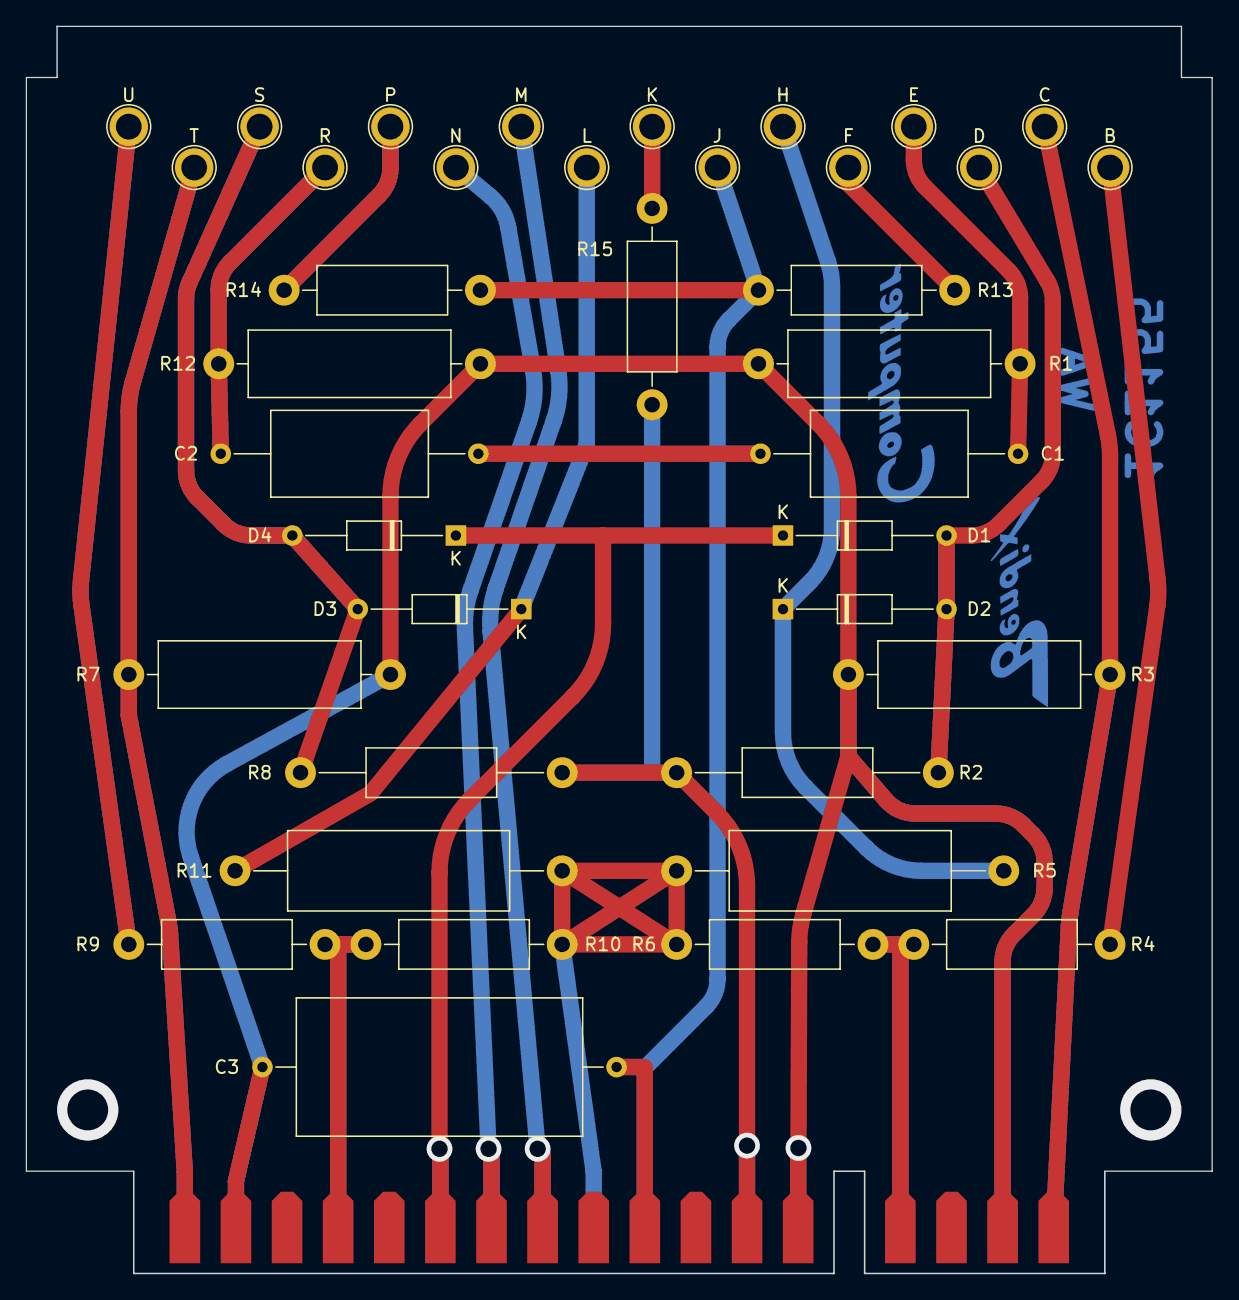
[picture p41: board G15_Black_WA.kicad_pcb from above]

Board: 2 copper layers, 92.1 x 96.8 mm, 39 parts (0 on the bottom side), 23 nets.

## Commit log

2022-02-02 Initial commit with Gold Flip Flop, Red Cathode Follower 1, and Blue Buffer Inverter
    [G15_Blue_BI.kicad_pcb, G15_Blue_BI.kicad_sch, G15_Gold_FF.kicad_pcb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]
2022-02-05 Green card Read Amplifier
    [G15_Green_RA.kicad_pcb, G15_Green_RA.kicad_sch]
2022-02-05 Update Readme, add schematic.
2022-02-05 Write Amplifier, Black card, added.
    [G15_Black_WA.kicad_pcb, G15_Black_WA.kicad_sch]
2022-02-05 Update Green Read Amp
    [G15_Green_RA.kicad_pcb]
2022-02-05 Write Amp schematic
2022-02-17 Cathode Follower 2 board
    [G15_Natural_CF2.kicad_pcb, G15_Natural_CF2.kicad_sch]
2022-02-18 All diode boards.
    [G15_Clock_Clamp.kicad_pcb, G15_Clock_Clamp.kicad_sch, G15_Diode_1.kicad_pcb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]
2022-02-18 Minor updates, and board files.
    [G15_Black_WA.kicad_pcb, G15_Blue_BI.kicad_pcb, G15_Clock_Clamp.kicad_pcb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]
